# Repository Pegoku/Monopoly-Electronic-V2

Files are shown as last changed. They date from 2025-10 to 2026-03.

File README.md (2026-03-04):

# Monopoly-Electronic-V2
This is a recreation of the classic Monopoly Electronic Banking game using modern technology. The project utilizes an ESP32 microcontroller to handle game logic and interactions, along with a Touch LCD display and RFID readers for player identification and transactions.

## Demo

[Demo Video](https://youtube.com/shorts/_shUK3fcT8k?feature=share)

## Images

### Final product

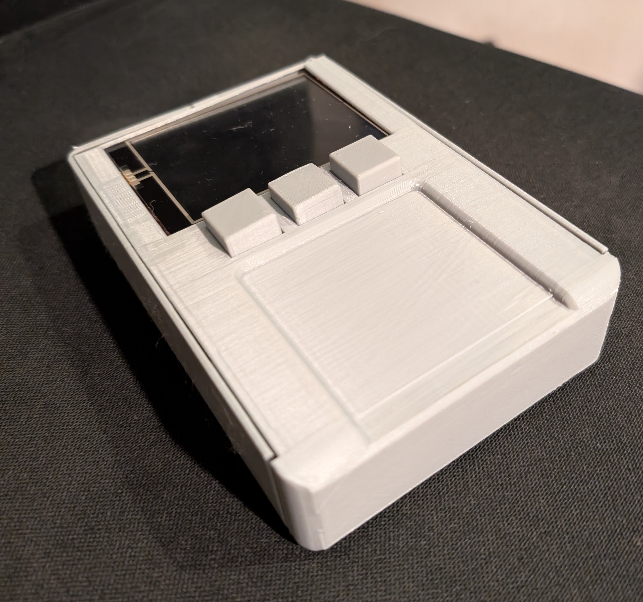
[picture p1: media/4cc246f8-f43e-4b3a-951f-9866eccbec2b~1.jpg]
Final Product


### CAD



<details>
<summary>Xray view - click to expand</summary>

Xray view

</details>

### PCB

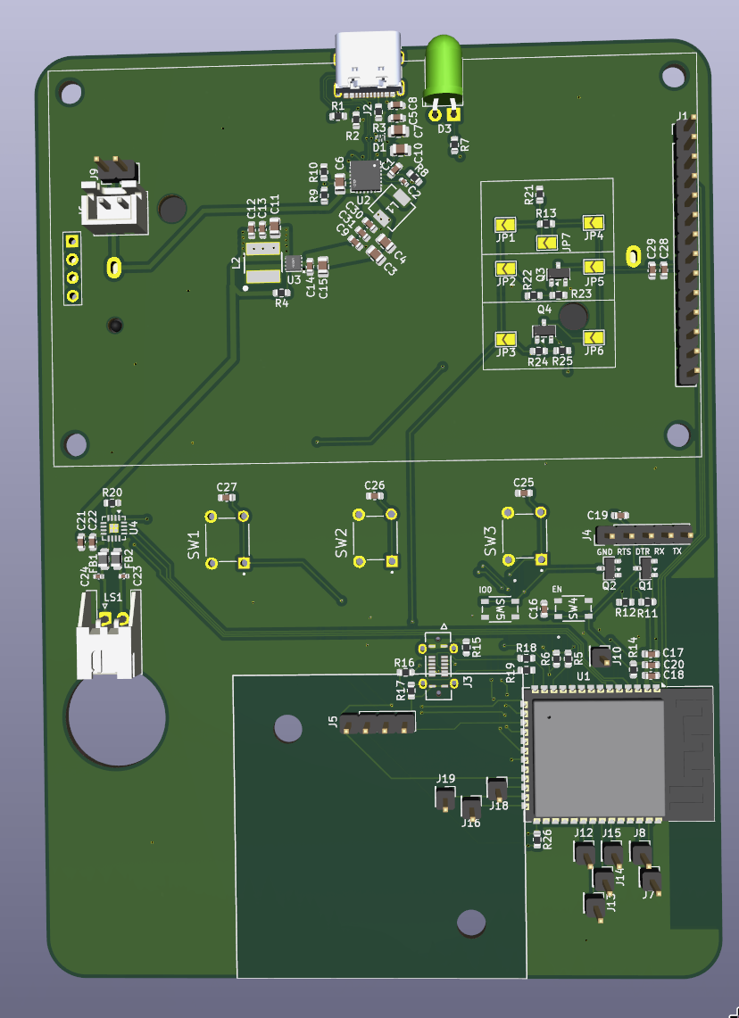
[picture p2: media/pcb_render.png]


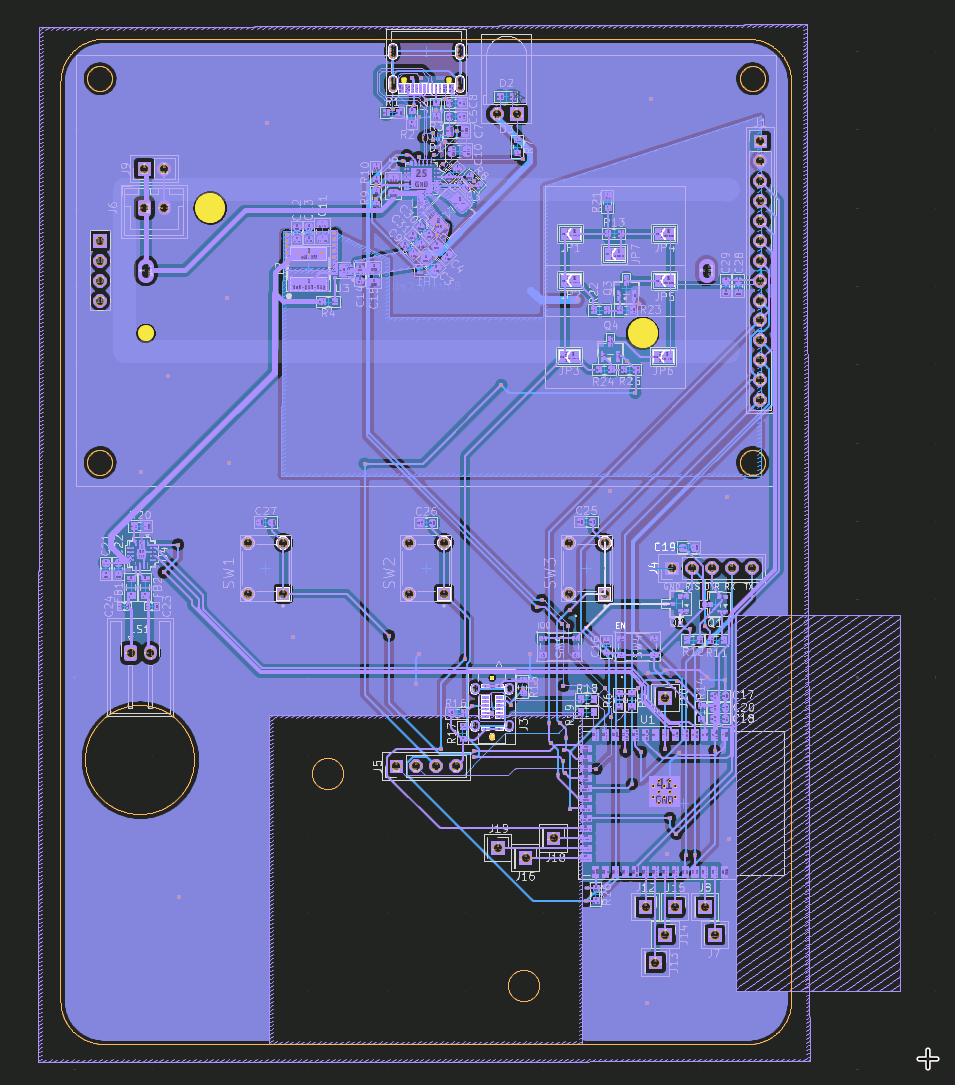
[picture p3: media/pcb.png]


<details>
<summary>Schematic - click to expand</summary>

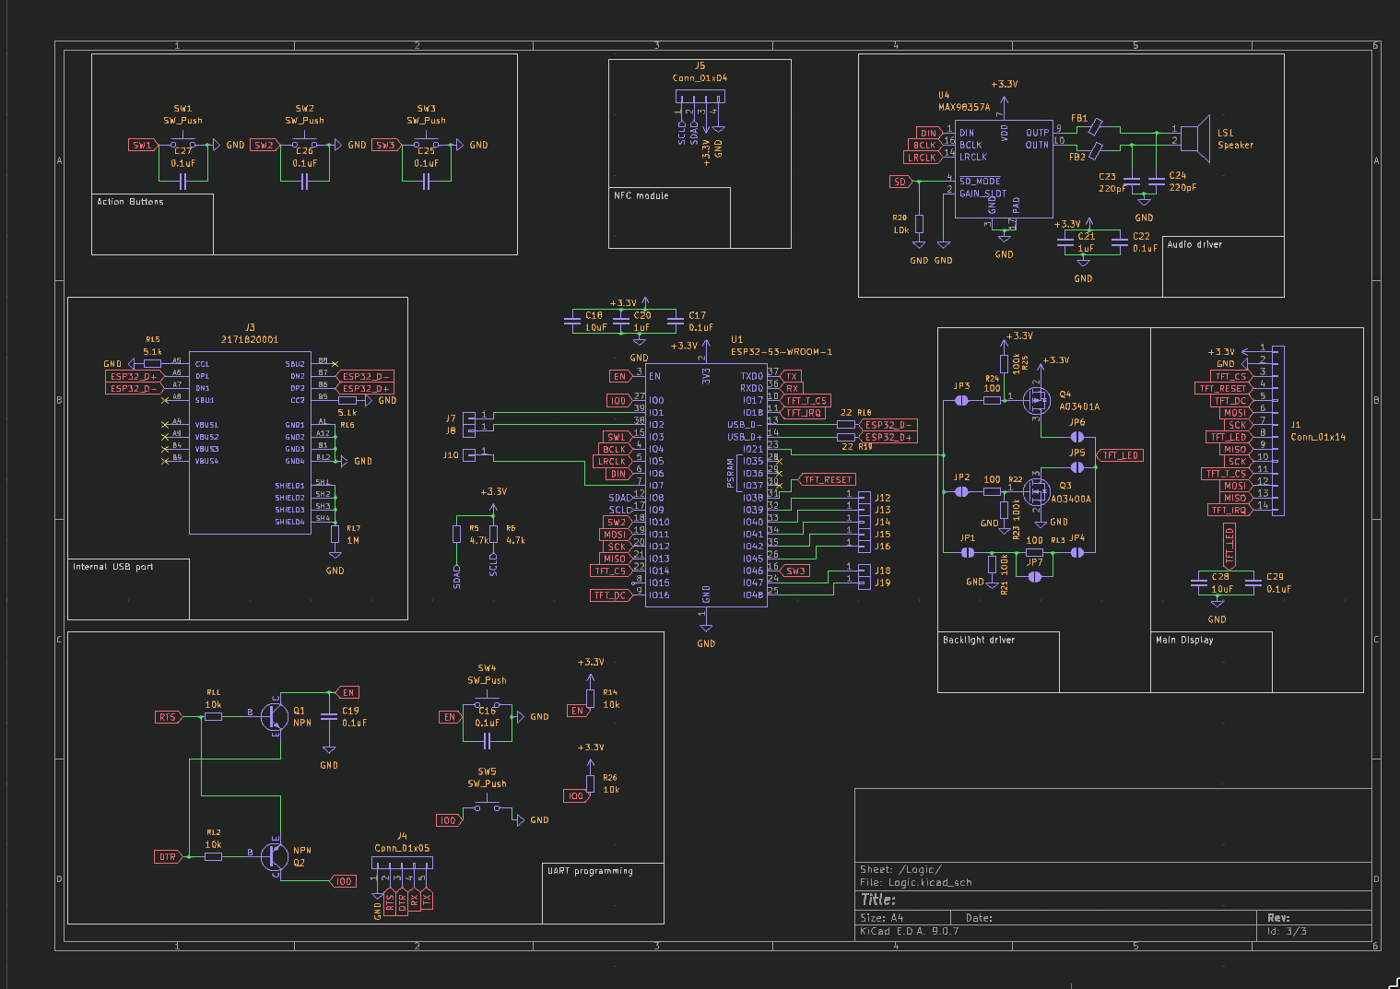
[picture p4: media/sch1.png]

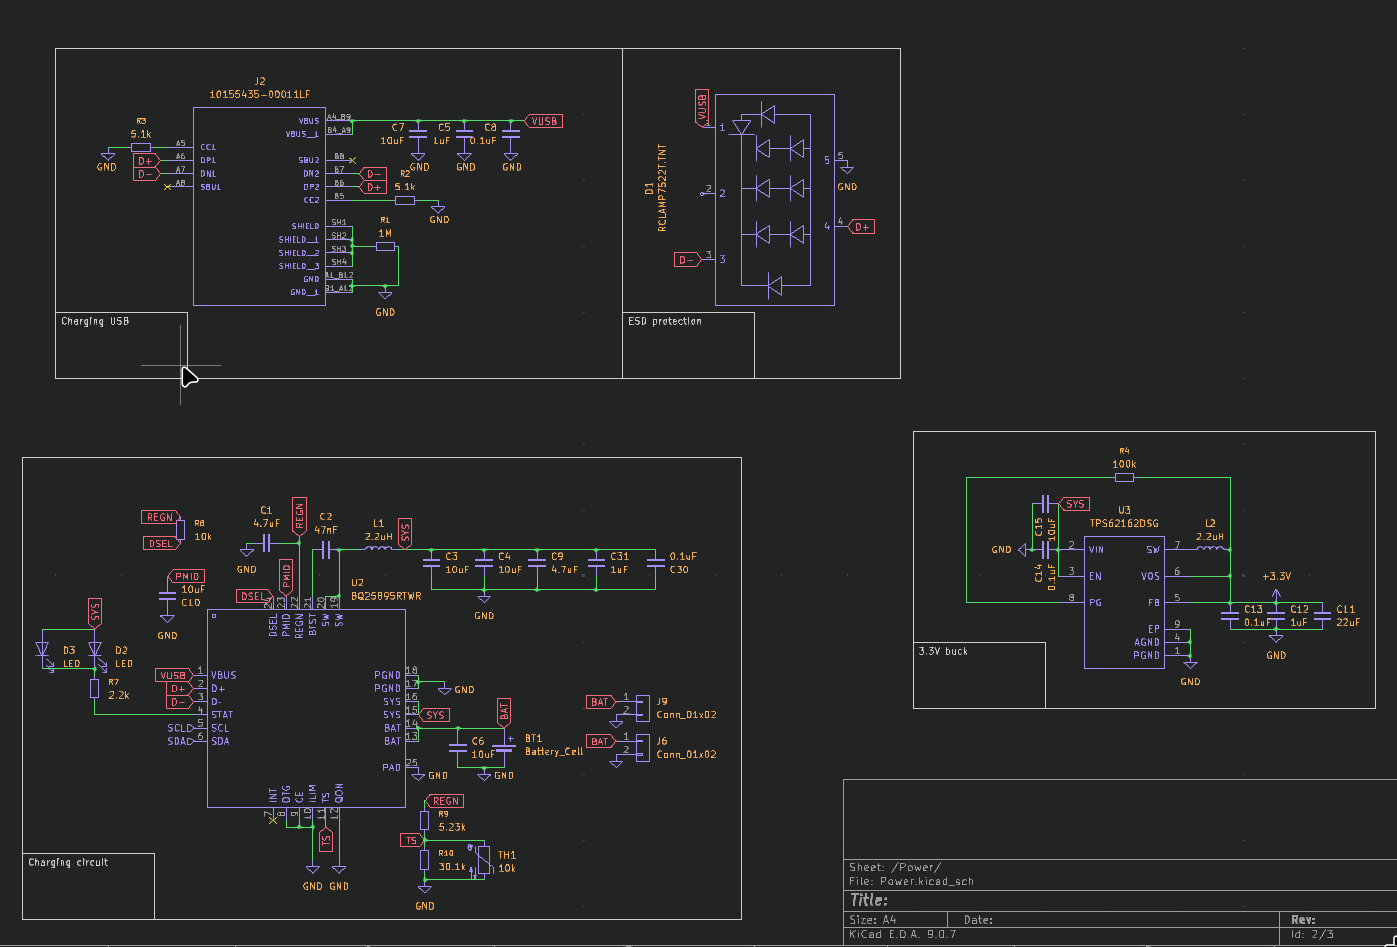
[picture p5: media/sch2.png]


</details>

## Features
- Electronic banking system using RFID cards for a more reliable process.
- Support for multiple players with individual RFID cards.
- Real-time game state updates displayed on the LCD.
- Sound effects for an immersive gaming experience.
- Customizable game rules and settings.

## UI

### Player registration

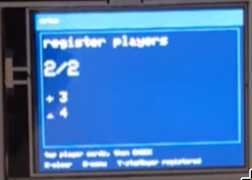
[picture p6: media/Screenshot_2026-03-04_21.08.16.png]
Player Registration


### Main game screen

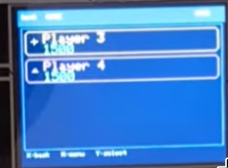
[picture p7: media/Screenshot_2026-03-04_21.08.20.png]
Main Game Screen


### Card interaction

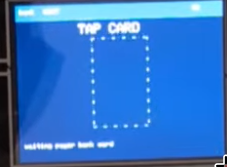
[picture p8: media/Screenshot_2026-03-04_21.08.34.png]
Card Interaction


## How the Game Works

Gameplay focuses on **NFC interaction instead of menus**.

Players throw the dice, and depending on where they land, they interact with the game console using their RFID cards. For example, if a player lands on a property, they can use their card to purchase it, or pay rent.

The game keeps track of each player's balance and properties, and updates the display accordingly. The use of RFID cards allows for a more seamless and engaging gaming experience, as players can quickly and easily interact with the game without navigating through complex menus. 

When a player has not enough money to pay rent or buy a property, they can choose to mortgage their properties or declare bankruptcy. The game will automatically handle these situations and update the game state accordingly.

If a player doesn't have enough money to pay rent, they will be bankrupt and removed from the game. The last player remaining with money wins the game.

### Card programming

To program the RFID cards, you can use the programming mode in the game console. Simply press the two side buttons simultaneously for 10 seconds to enter programming mode. Then, place the card you want to program on the console and follow the prompts on the LCD display to assign a player name, land.

## BOM (Bill of Materials)
| Index | MPN | Description | pack quantity | price | TOTAL  |
| ----- | --- | --- | --- | ----- | --- |
| 1 | BQ25895RTWR | IC BATT CHG LI-ION 1CELL 24WQFN | 2 | 6.58  | 178.39 |
| 2 | TPS62162DSGR | IC REG BUCK 3.3V 1A 8WSON | 2 | 3.14  | |
| 3 | RCLAMP7522T.TNT | TVS DIODE 5VWM 25VC SLP1007N5T | 2 | 3.14  | |
| 4 | ESP32-S3-WROOM-1-N8R8 | RF TXRX MOD BT WIFI PCB TH SMD | 2 | 12.26 | |
| 5 | NFC RFID Wireless Module | https://es.aliexpress.com/item/1005006837891461.html | 1 | 4.45  | |
| 6 | MF1 1k NFC card | https://es.aliexpress.com/item/1005006127590709.html | 50 | 12.91 | |
| 7 | 1043P | BATTERY HOLDER 18650 PC PIN | 2 | 5.62  | |
| 8 | F51L-1A7H1-11020 | CONN FFC FPC BOTTOM 20POS 1MM RA | 2 | 1.12  | |
| 9 | 10155435-00011LF | USB TYPE C R/A SMT 16PIN | 2 | 1.56  | |
| 10 | NSR10F20NXT5G | DIODE SCHOTTKY 20V 1A 2DSN | 2 | 0.3 | |
| 11 | SM5817PL-TP | DIODE SCHOTTKY 20V 1A SOD123FL | 3 | 0.45  | |
| 12 | BLM21PG221SN1D | FERRITE BEAD 220 OHM 0805 1LN | 3 | 0.33  | |
| 13 | GRM21BR61C106KE15K | CAP CER 10UF 16V X5R 0805 | 10 | 0.81  | |
| 14 | GRM21BR61A226ME51L | CAP CER 22UF 10V X5R 0805 | 10 | 1.14  | |
| 15 | GRM188R72A104KA35D | CAP CER 0.1UF 100V X7R 0603 | 17 | 1.48  | |
| 16 | 104CDMCCDS-220MC | FIXED IND 22UH 5A 66 MOHM SMD | 2 | 1.6 | |
| 17 | 74404054022 | FIXED IND 2.2UH 3.8A 19 MOHM SMD | 2 | 2.4 | |
| 18 | 104CDMCCDS-2R2MC | FIXED IND 2.2UH 15A 7 MOHM SMD | 2 | 1.6 | |
| 19 | SRP4020TA-2R2M | FIXED IND 2.2UH 4A 61 MOHM SMD | 2 | 2.04  | |
| 20 | BC847B | TRANS NPN 45V 0.1A SOT23-3 | 4 | 0.44  | |
| 21 | CL10B105KP8NNNC | CAP CER 1UF 10V X7R 0603 | 11 | 0.06  | |
| 22 | GRM188Z71A475ME15D | CAP CER 4.7UF 10V X7R 0603 | 11 | 1.34  | |
| 23 | GRM188Z71A475ME15D | CAP CER 4.7UF 10V X7R 0603 | 11 | 1.34  | |
| 24 | GRM1555C1H221JA01D | CAP CER 220PF 50V C0G/NP0 0402 | 11 | 0.36  | |
| 25 | GCJ188R71H473KA12D | CAP CER 0.047UF 50V X7R 0603 | 11 | 0.96  | |
| 26 | GRM155R71E473KA88D | CAP CER 0.047UF 25V X7R 0402 | 10 | 0.22  | |
| 27 | ERJ-3EKF1004V | RES SMD 1M OHM 1% 1/10W 0603 | 11 | 0.37  | |
| 28 | ERJ-PA3F5101V | RES SMD 5.1K OHM 1% 1/3W 0603 | 11 | 0.75  | |
| 29 | ERJ-PA3F1003V | RES SMD 100K OHM 1% 1/3W 0603 | 11 | 0.75  | |
| 30 | ERJ-PA3F4701V | RES SMD 4.7K OHM 1% 1/3W 0603 | 11 | 0.75  | |
| 31 | ERJ-PA3F2201V | RES SMD 2.2K OHM 1% 1/3W 0603 | 11 | 0.75  | |
| 32 | ERJ-PA3F1002V | RES SMD 10K OHM 1% 1/3W 0603 | 11 | 0.75  | |
| 33 | ERJ-3EKF5231V | RES SMD 5.23K OHM 1% 1/10W 0603 | 11 | 0.37  | |
| 34 | ERJ-PB3D3012V | RES SMD 30.1K OHM 0.5% 1/5W 0603 | 11 | 0.81  | |
| 35 | ERJ-3EKF1202V | RES SMD 12K OHM 1% 1/10W 0603 | 11 | 0.37  | |
| 36 | ERJ-3EKF22R0V | RES SMD 22 OHM 1% 1/10W 0603 | 11 | 0.37  | |
| 37 | NCU18XH103F6SRB | THERMISTOR NTC 10KOHM 3380K 0603 | 2 | 0.28  | |
| 38 | TL1105BF160Q | SWITCH TACTILE SPST-NO 0.05A 12V | 6 | 1.2 | |
| 39 | SKRPABE010 | SWITCH TACTILE SPST-NO 0.05A 16V | 4 | 0.84  | |
| 40 | SLR-56VRT32 | LED RED DIFFUSED T-1 3/4 T/H | 3 | 1.59  | |
| 41 | AO3400A | 30V 5.8A 35MR@10V,5.8A 1.4W 1.4V | 3 | 0.54  | |
| 42 | AO3401A | 30V 4.1A 65MR@10V,4.2A 350MW 1.3 | 3 | 0.6 | |
| 43 | Rubber Feets | https://es.aliexpress.com/item/1005007247599206.html | 4 | 3.22  | |
| 44 | PCB | JLCPCB | 1 | 41.59 | |
| 45 | M3x16 (DIN912) | https://es.aliexpress.com/item/1005007118809249.html | 55 | 4.67  | |
| 46 | M2.5x6 (DIN7991) | https://es.aliexpress.com/item/1005007118809249.html | 55 | 4.19  | |
| 47 | heatset inserts M2.5x3.5 | https://es.aliexpress.com/item/1005007342105110.html | 50 | 3.4 | |
| 48 | heatset inserts M3x4.2 | https://es.aliexpress.com/item/1005007342105110.html | 50 | 3.92  | |
| 49 | 8R 0.5W 40mm Speaker | https://es.aliexpress.com/item/1005007949154095.html | 1 | 3.51  | |
| 50 | 3.2" ST7789 with touch | https://es.aliexpress.com/item/1005009929917954.html | 1 | 10.37 | |
| 51 | heatset insert pinecil | https://es.aliexpress.com/item/1005008145530885.html | 1 | 11.89 | |
| 52 | Digikey VAT | | 1 | 12.89 | |

## License

This work is licensed under a
[Creative Commons Attribution-NonCommercial 4.0 International License][cc-by-nc].

[][cc-by-nc]

[cc-by-nc]: https://creativecommons.org/licenses/by-nc/4.0/
[cc-by-nc-image]: https://licensebuttons.net/l/by-nc/4.0/88x31.png
[cc-by-nc-shield]: https://img.shields.io/badge/License-CC%20BY--NC%204.0-lightgrey.svg

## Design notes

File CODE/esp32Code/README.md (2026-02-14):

# ESP32 Monopoly Electronic Banking Firmware

Minimal card-driven firmware for ESP32 + ST7789 + PN532, matching the web emulator flow.

## Build

```bash
pio run
```

## Flash

```bash
pio run -t upload
```

## Implemented modules

- `src/nfc_manager.cpp`
- `src/card_manager.cpp`
- `src/game_logic.cpp`
- `src/display_ui.cpp`
- `src/battery_manager.cpp`
- `src/sound_manager.cpp`

## NFC block layout (Mifare Classic)

- Player bank card: block `4`
- Property card: block `8`
- Event card: block `12`

Each block stores:

- bytes `[0..2]`: magic `MB2`
- byte `[3]`: version
- byte `[4]`: card type
- remaining bytes: card payload

## Notes

- Game state follows card-driven state machine (`HOME`, `WAIT_CARD`, `PROPERTY_*`, `EVENT`, `AUCTION`, `DEBT`, `GO`, `JAIL`, `WINNER`).
- UI is intentionally sparse and monochrome-like, based on your reference photos.
- Property ownership/rent level are read/written from property cards.

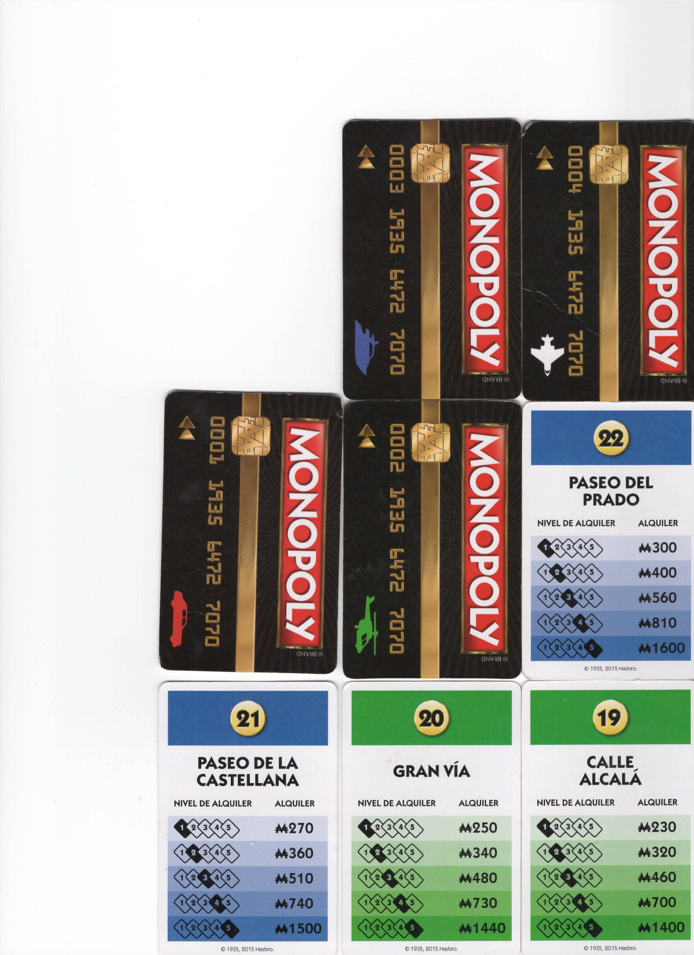
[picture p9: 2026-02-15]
CODE/CardGenerator/reference_page-3.png

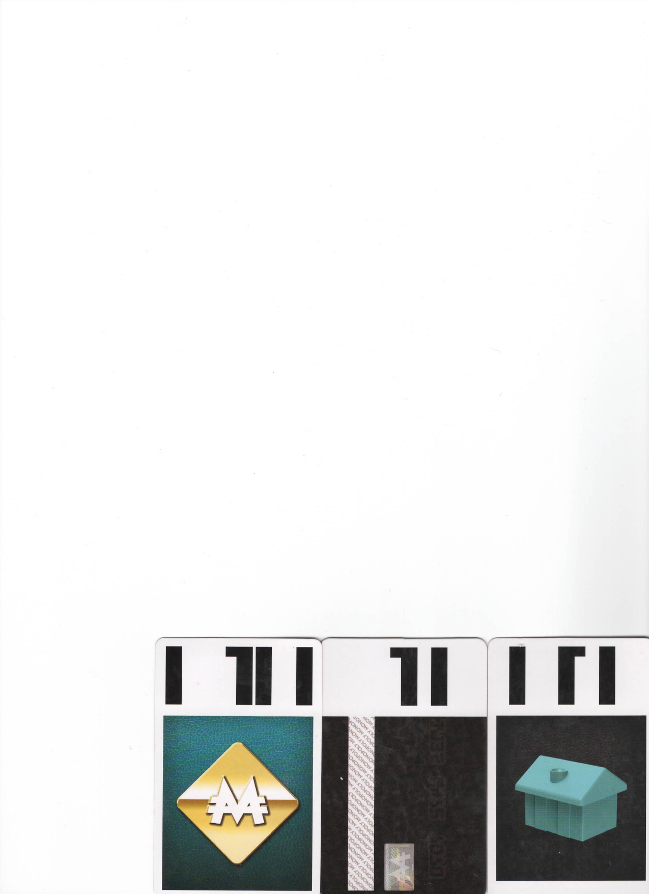
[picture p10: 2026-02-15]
CODE/CardGenerator/reference_page-4.png

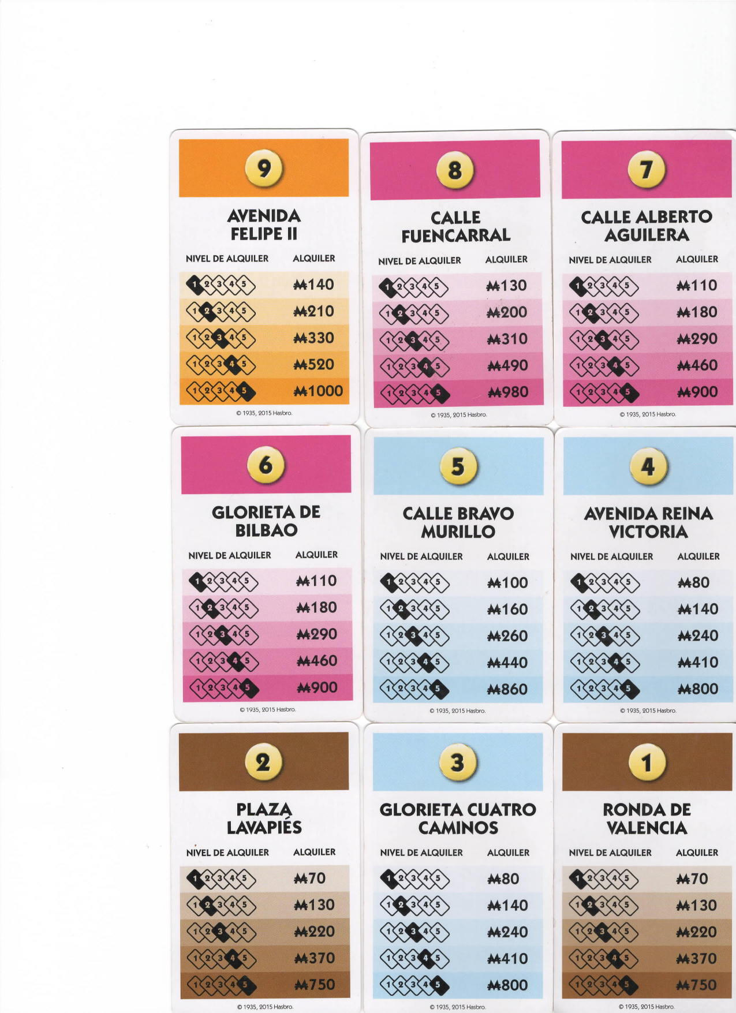
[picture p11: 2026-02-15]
CODE/CardGenerator/reference_page-1.png

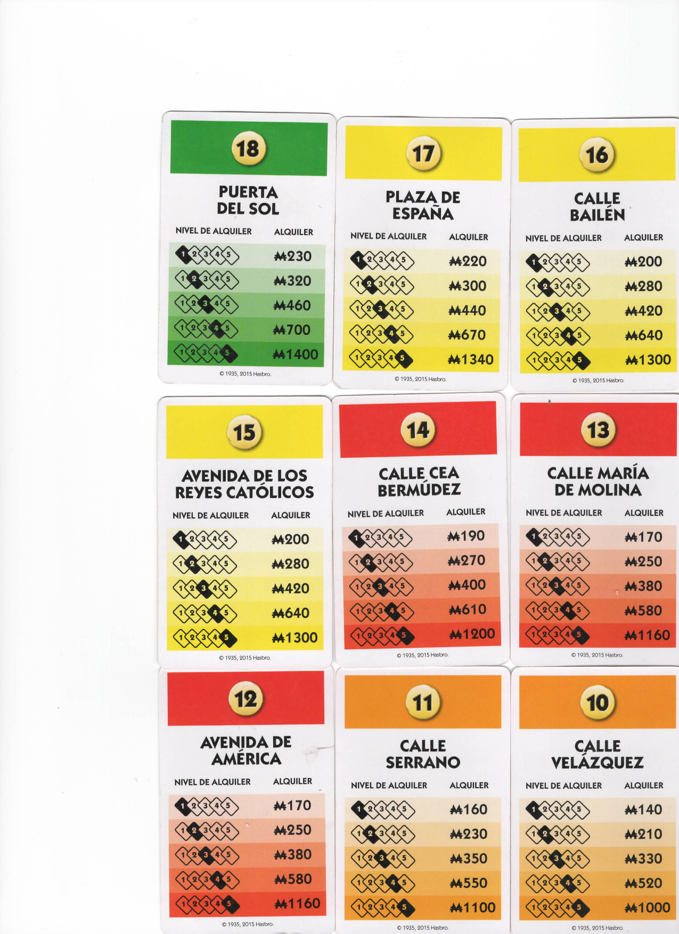
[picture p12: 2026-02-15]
CODE/CardGenerator/reference_page-2.png

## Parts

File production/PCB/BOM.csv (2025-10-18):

Designator | Footprint | Quantity | Value
BT1 | BAT-TH_1043P | 1 | Battery_Cell
C1, C9 | 603 | 2 | 4.7uF
C10, C15, C3, C4, C6, C7 | 805 | 6 | 10uF
C11 | 805 | 1 | 22uF
C12, C20, C21, C31, C5 | 603 | 5 | 1uF
C13, C14, C16, C17, C19, C22, C25, C26, C27, C29, C30, C8 | 603 | 12 | 0.1uF
C18, C28 | 603 | 2 | 10uF
C2 | 402 | 1 | 47nF
C23, C24 | 402 | 2 | 220pF
D1 | SLP1007N5T_L1.0-W0.7-P0.35-BL | 1 | RCLAMP7522T.TNT
D2 | 603 | 1 | LED
D3 | LED_D5.0mm_Horizontal_O1.27mm_Z3.0mm | 1 | LED
FB1, FB2 | 805 | 2 | BLM21PG221SN1D
J1 | 240X320 TFT 3.2 display | 1 | Conn_01x14
J10, J12, J13, J14, J15, J16, J18, J19, J7, J8 | PinHeader_1x01_P2.54mm_Vertical | 10 | Conn_01x01
J2 | AMPHENOL_10155435-00011LF | 1 | 10155435-00011LF
J3 | MOLEX_2171820001 | 1 | 2171820001
J4 | PinHeader_1x05_P2.54mm_Vertical | 1 | Conn_01x05
J5 | PinHeader_1x04_P2.54mm_Vertical | 1 | Conn_01x04
J6 | JST_XH_B2B-XH-A_1x02_P2.50mm_Vertical | 1 | Conn_01x02
J9 | PinHeader_1x02_P2.54mm_Vertical | 1 | Conn_01x02
L1 | IND_SRP4020TA_BRN | 1 | 2.2uH
L2 | WE-LQS_5040 | 1 | 2.2uH
LS1 | JST_XH_S2B-XH-A-1_1x02_P2.50mm_Horizontal | 1 | Speaker
Q1, Q2 | SOT-23-231 | 2 | NPN
Q3 | SOT-23 | 1 | AO3400A
Q4 | SOT-23 | 1 | AO3401A
R1, R17 | 603 | 2 | 1M
R10 | 603 | 1 | 30.1k
R11, R12, R14, R20, R26, R8, TH1 | 603 | 7 | 10k
R13, R22, R24 | 603 | 3 | 100
R15, R16, R2, R3 | 603 | 4 | 5.1k
R18, R19 | 603 | 2 | 22
R21, R23, R25, R4 | 603 | 4 | 100k
R5, R6 | 603 | 2 | 4.7k
R7 | 603 | 1 | 2.2k
R9 | 603 | 1 | 5.23k
SW1, SW2, SW3 | SW_TL1105BF160Q | 3 | SW_Push
SW4, SW5 | SW4_SKRPABE010_ALPS | 2 | SW_Push
U1 | ESP32-S3-WROOM-1 | 1 | ESP32-S3-WROOM-1
U2 | QFN-24_L4.0-W4.0-P0.50-TL-EP2.7 | 1 | BQ25895RTWR
U3 | WSON-8_L2.0-W2.0-P0.50-TL-EP | 1 | TPS62162DSG
U4 | TQFN-16-1EP_3x3mm_P0.5mm_EP1.23x1.23mm | 1 | MAX98357A

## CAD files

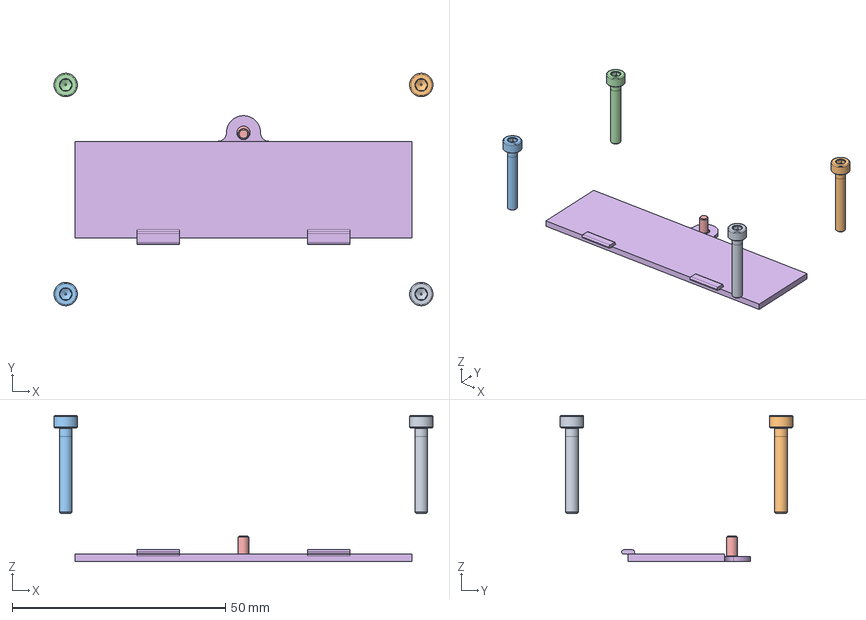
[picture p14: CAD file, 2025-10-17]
CAD/MAIN.FCStd
88.8 x 54.5 x 34.3 mm
M3x20-Screw
M3x20-Screw004
M3x20-Screw005
M3x20-Screw006
M2.5x6-Screw

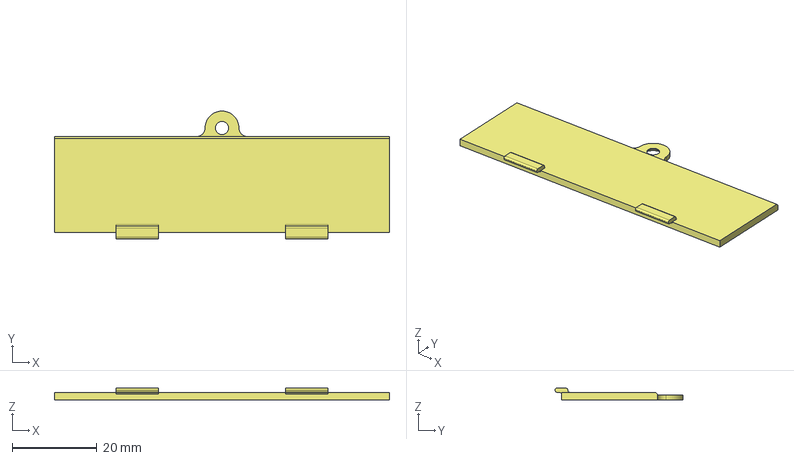
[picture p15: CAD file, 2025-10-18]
production/CAD/CaseBatteryTab.step
79.0 x 30.2 x 2.80 mm

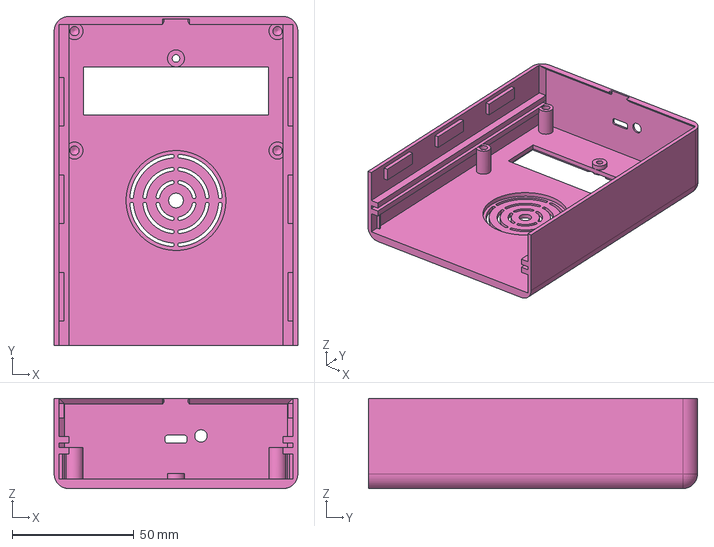
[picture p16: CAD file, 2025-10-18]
production/CAD/CaseBase.step
100.0 x 135.0 x 37.0 mm

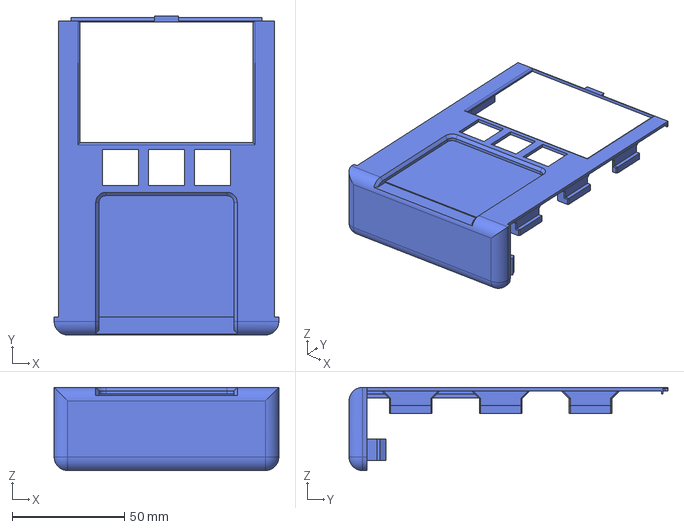
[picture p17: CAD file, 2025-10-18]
production/CAD/CaseCover.step
100.0 x 142.0 x 37.0 mm

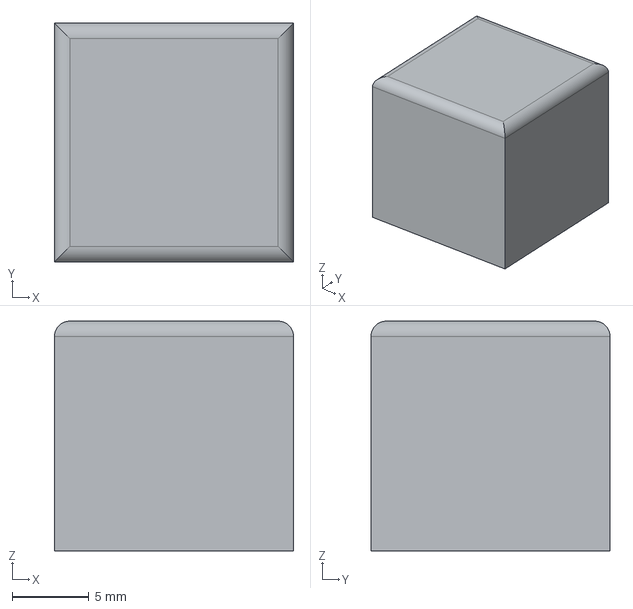
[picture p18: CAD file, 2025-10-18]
production/CAD/CaseButton.step
15.6 x 15.6 x 15.0 mm

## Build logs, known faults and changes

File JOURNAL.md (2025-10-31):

<!--
  ===================    !!READ THIS NOTICE!!   ====================
  DO NOT edit this file manually. Your changes WILL BE OVERWRITTEN!
  This journal is auto generated and updated by Hack Club Blueprint.
  To edit this file, please edit your journal entries on Blueprint.
  ==================================================================
-->

## 10/3/2025 - Simple draft of the project  

I drew a simple draft of the project. 
For this project, I would like to have the following features:
- MCU (maybe Wi-Fi for future mobile/web integration)
- NFC reader
- TFT display
- Speaker
- Action buttons
- Battery (at least a few hours of battery life, maybe an 18650 or multiple AA batteries)



## 10/4/2025 - Research possible parts  

I've been searching for the possible parts I could use for my project. I've seen many options, some more expensive, others cheaper. I have ended up selecting most of the parts from Digikey, due to the huge variety and fast shipping.
I've created a [digikey list](https://www.digikey.es/en/mylists/list/QVK6J72RAV) with all the parts that will be used.
[https://www.digikey.es/en/mylists/list/QVK6J72RAV](https://www.digikey.es/en/mylists/list/QVK6J72RAV)
  

## 10/6/2025 11 AM - Work on the Power/battery part of the schematic  

I have been working on the battery part of the schematic.
I have wired most of the BQ25895RTWR, and USB-C port. Only the 3.3V buck is left.
I arrived to the conclusion about not needing the 5V from the BQ25895RTWR, as everything will be running from 3.3V, so I disabled it.


## 10/6/2025 8 PM - Work on the Logic part of the schematic  

I've been working on the Logic part of the shematic. The programming part should be done, I used a vertical USB-C port I'll have hidden inside, and regular UART as a fallback.
I also added an I2S Audio driver (MAX98357A) as I didn't want to just use PWM, but didn't need something too fancy for simple sound effects.
Now I'll just need to add a display, which I'll be changing to a bigger one. Maybe, I'll get one with touch support



## 10/7/2025 - Find a possible suitable LCD  

After all, I decided for an SPI TFT LCD. I'll be going with a 3.2" touch ST7789 SPI display. it seems to be big enough, and have more than enough resolution for my project. Also, it seems to be supported with some libraries.
It also has touch, just in case I ever want to use it.


## 10/8/2025 - Finish Schematic routing  

I finished all the schematic routing (PCB, NFC, etc). The display seemed hard, but it really was just two SPI devices (Display and Touch).
I think everything should be done now. I only need to select all components (resistors, capacitors, etc) so I can use the correct footprints.




## 10/10/2025 - Assign footprints + backlight driving options  

I assigned all the necessary footprints to the symbols, and I also chose which parts I will be using for the PCB. I added all of them to the [Digikey BOM](https://www.digikey.es/en/mylists/list/QVK6J72RAV).
Also, as I don't currently have the display, nor, know how the LED backlight is connected, I added multiple driving circuits. They are all disabled by default (have to use jumpers). And when I get all the components, I will use the correct driver method.



## 10/11/2025 10 AM - Groups to the schematic and start placing components  

I have reordered the schematic so I can more easily reference the components and, at a glance, find them.
I've used rectangles and text so I can name all the groups.





Then, I've started placing the components in the PCB. I'll start with what I always do, group the components and try to place them with their "ideal" placement.
This is what I've got so far:







## 10/11/2025 8 PM - Finish placing the components  

I finished placing all the components in their "ideal" place. Due to the bigger than firstly planned display, the PCB ended up being 93.3 x 128.35 mm. which isn't a lot bigger than intented, but it will make the final device bigger, not a huge dealbreaker, though.



## 10/12/2025 - Start routing top part of the pcb  

I have started routing part of the pcb. as I already had all the components placed, I only have to connect them, which isn't too hard. I'm also using copper pours for some parts of the pcb, eg. buck.
For now, I've routed the usb charge connector, battery circuit and charger and buck.



## 10/13/2025 - Finish routing the PCB  

I finished routing all the PCB. It should now be done. I will now start designing the case. I will try to make it similar to the drawing I did before (first journal entry), while also having the essence of the original [Monopoly Electronic i have](https://imgs.search.brave.com/97KW8I4h7B_5Km5_sD36x9mR6GnvyAEScB285sH_O2Q/rs:fit:860:0:0:0/g:ce/aHR0cHM6Ly9pLmVi/YXlpbWcuY29tL2lt/YWdlcy9nLzBPQUFB/T1N3aEExbWx3Y0sv/c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).





## 10/15/2025 11 AM - Start Cadding  

I have started the CAD design. I've added a speaker grill (spent too much time making it look good, battery pocket for easy battery replacement (if necessary) and pcb "rails" so the pcb can easily be mounted. 
For now I'll be doing only the "raw" parts of the case. then I'll add more complex/visual features.

This is what I've got so far:





## 10/15/2025 7 PM - Finish base and design clipping mechanism  

I've finished designing the base, and I've started designing the cover of the case. I'm going with a "slide and click" mechanism. This way it will be easy to assemble, and also, there won't be any visible screws, which is a must (if I can) for this design.



PS: this is going to be VERY overengineered... 😭  

## 10/17/2025 - Finish CAD (Hopefully)  

It took longer than expected, but, finally, after a lot of time and overengineering, I finished all the CAD!
I tried to keep as many of the visual features as I could while making sure it actually works.
I ~~think~~ know it could have been made a lot simpler, but I wanted to challenge myself.

This is the final result.





## 10/18/2025 - Prepare GitHub Repo for submitting  

I got the repo ready for submitting. Luckily I alredy had most of the files, exports, etc done. I just had to copy them to the correct folders, write a README.md, add images, check, export and convert to MarkDown the BOM, and write this journal entry.

REPO: https://github.com/Pegoku/Monopoly-Electronic-V2



## 10/19/2025 - Learning LVGL  

I had to have some code for this project, so I could submit it, so I started to learn LVGL, so when I receive the parts, I can assemble them and can start to use it to test the display. I didn't do the full game for now, as I don't want to build it in regular cpp (not arduino framework) due to it maybe not working as intended on the final device.

For now, I did a simple 5 button test. When a button is pressed, a random number is generated. This is a start, and I will be able to use what I learnt for this for the final build.


## 10/31/2025 - Tests before order  

Before I order the PCB, I wanted to do some tests with the display, so I bought an esp32-S3 devboard and a display so I could learn LVGL, and check the schematic is correct.

I was able to get the display to work!
PXL_20251030_213944654.MP

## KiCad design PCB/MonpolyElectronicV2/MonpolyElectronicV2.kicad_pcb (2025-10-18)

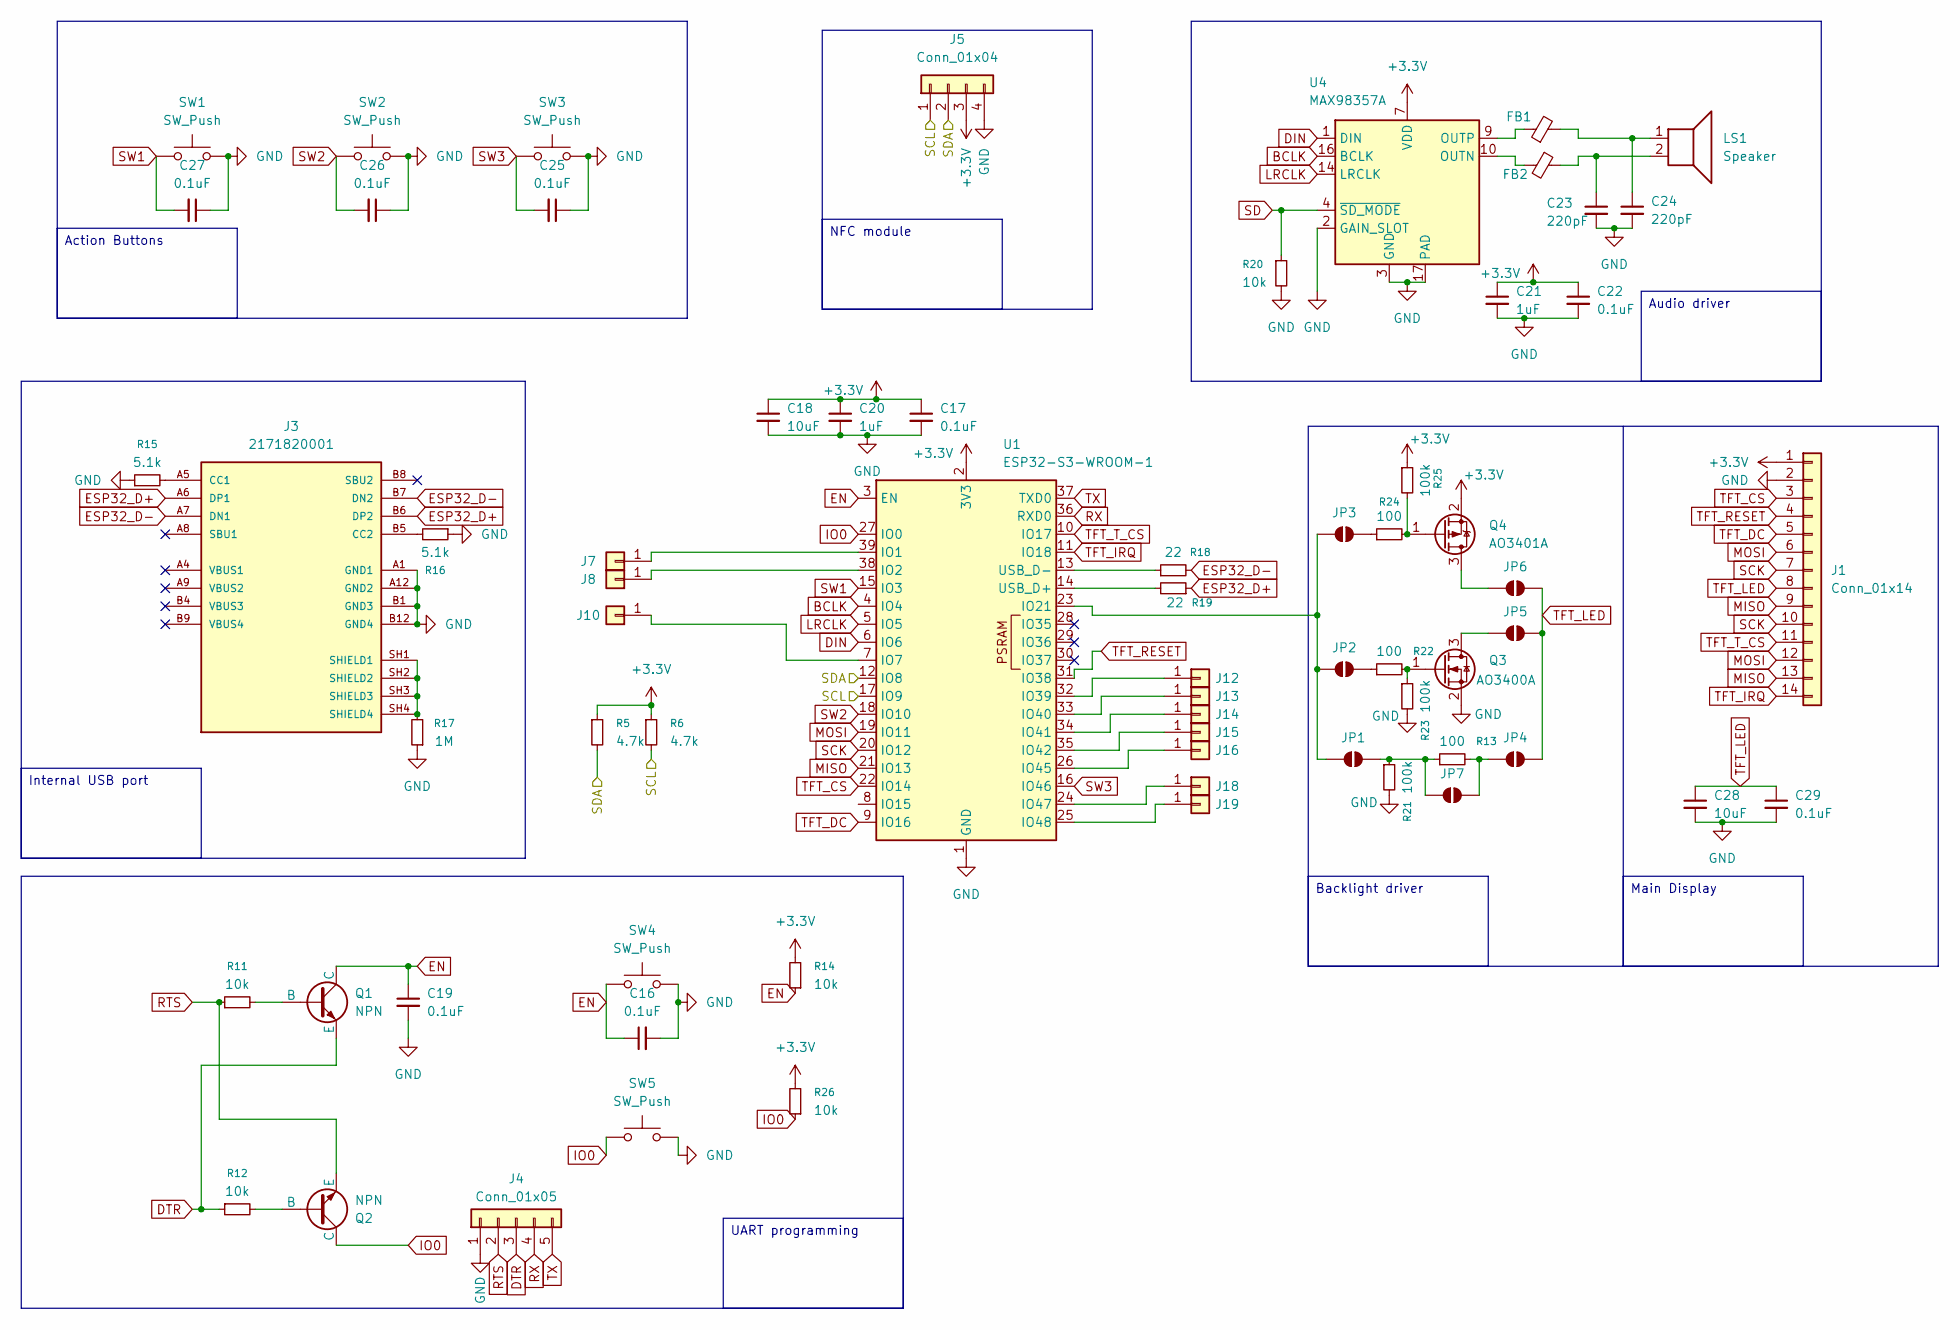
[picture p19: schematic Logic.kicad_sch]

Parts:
C16, C17, C19, C22, C25, C26, C27, C29: 0.1uF; C_0603_1608Metric
C18, C28: 10uF; C_0603_1608Metric
C20, C21: 1uF; C_0603_1608Metric
C23, C24: 220pF; C_0402_1005Metric
FB1, FB2: BLM21PG221SN1D; L_0805_2012Metric
J1: Conn_01x14; 240X320 TFT 3.2 display
J3: 2171820001; MOLEX_2171820001; PARTREV B
J4: Conn_01x05; PinHeader_1x05_P2.54mm_Vertical
J5: Conn_01x04; PinHeader_1x04_P2.54mm_Vertical
J7, J8, J10, J12, J13, J14, J15, J16, J18, J19: Conn_01x01; PinHeader_1x01_P2.54mm_Vertical
JP1, JP2, JP3, JP4, JP5, JP6, JP7: SolderJumper_2_Open; SolderJumper-2_P1.3mm_Open_TrianglePad1.0x1.5mm
LS1: Speaker; JST_XH_S2B-XH-A-1_1x02_P2.50mm_Horizontal
Q1, Q2: NPN; SOT-23-231
Q3: AO3400A; SOT-23
Q4: AO3401A; SOT-23
R5, R6: 4.7k; R_0603_1608Metric
R11, R12, R14, R20, R26: 10k; R_0603_1608Metric
R13, R22, R24: 100; R_0603_1608Metric
R15, R16: 5.1k; R_0603_1608Metric
R17: 1M; R_0603_1608Metric
R18, R19: 22; R_0603_1608Metric
R21, R23, R25: 100k; R_0603_1608Metric
SW1, SW2, SW3: SW_Push; SW_TL1105BF160Q
SW4, SW5: SW_Push; SW4_SKRPABE010_ALPS
U1: ESP32-S3-WROOM-1
U4: MAX98357A; TQFN-16-1EP_3x3mm_P0.5mm_EP1.23x1.23mm

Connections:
+3.3V: C17.1, C18.1, C20.1, C21.1, C22.1, J1.1, J5.3, Q4.2 (S), R5.1, R6.1, R14.2, R25.1, R26.2, U1.2 (3V3), U4.7 (VDD), U4.8 (VDD); also elsewhere on the board
/Logic/SCL: J5.1, R6.2, U1.17 (IO9); also elsewhere on the board
/Logic/SDA: J5.2, R5.2, U1.12 (IO8); also elsewhere on the board
BCLK: U1.4 (IO4), U4.16 (BCLK)
DIN: U1.6 (IO6), U4.1 (DIN)
DTR: J4.3, Q1.3 (E), R12.1
EN: C16.1, C19.1, Q1.1 (C), R14.1, SW4.1, U1.3 (EN)
ESP32_D+: J3.A6 (DP1), J3.B6 (DP2), R19.1
ESP32_D-: J3.A7 (DN1), J3.B7 (DN2), R18.2
GND: C16.2, C17.2, C18.2, C19.2, C20.2, C21.2, C22.2, C23.2, C24.2, C25.1, C26.1, C27.1, C28.2, C29.2, J1.2, J3.A1 (GND1), J3.A12 (GND2), J3.B1 (GND3), J3.B12 (GND4), J4.1, J5.4, Q3.2 (S), R15.1, R16.1, R17.1, R20.2, R21.2, R23.2, SW1.2, SW2.2, SW3.2, SW4.2, SW5.2, U1.1 (GND), U1.40 (GND), U1.41 (GND), U4.2 (GAIN_SLOT), U4.3 (GND), U4.11 (GND), U4.15 (GND), U4.17 (PAD); also elsewhere on the board
IO0: Q2.1 (C), R26.1, SW5.1, U1.27 (IO0)
LRCLK: U1.5 (IO5), U4.14 (LRCLK)
MISO: J1.9, J1.13, U1.21 (IO13)
MOSI: J1.6, J1.12, U1.19 (IO11)
unnamed: C23.1, FB2.1, LS1.2
unnamed: C24.1, FB1.2, LS1.1
unnamed: J3.A5 (CC1), R15.2
unnamed: J3.B5 (CC2), R16.2
unnamed: J3.SH1 (SHIELD1), J3.SH2 (SHIELD2), J3.SH3 (SHIELD3), J3.SH4 (SHIELD4), R17.2
unnamed: J7.1, U1.39 (IO1)
unnamed: J8.1, U1.38 (IO2)
unnamed: J10.1, U1.7 (IO7)
unnamed: J12.1, U1.32 (IO39)
unnamed: J13.1, U1.33 (IO40)
unnamed: J14.1, U1.34 (IO41)
unnamed: J15.1, U1.35 (IO42)
unnamed: J16.1, U1.26 (IO45)
unnamed: J18.1, U1.24 (IO47)
unnamed: J19.1, U1.25 (IO48)
unnamed: JP1.1 (A), JP7.2 (B), R13.1, R21.1
unnamed: JP1.2 (B), JP2.2 (B), JP3.2 (B), U1.23 (IO21)
unnamed: JP2.1 (A), R22.1
unnamed: JP3.1 (A), R24.1
unnamed: JP4.2 (B), JP7.1 (A), R13.2
unnamed: JP5.2 (B), Q3.3 (D)
unnamed: JP6.2 (B), Q4.3 (D)
unnamed: Q1.2 (B), R11.2
unnamed: Q2.2 (B), R12.2
unnamed: Q3.1 (G), R22.2, R23.1
unnamed: Q4.1 (G), R24.2, R25.2
unnamed: R19.2, U1.14 (USB_D+)
unnamed: R18.1, U1.13 (USB_D-)
unnamed: FB2.2, U4.10 (OUTN)
unnamed: FB1.1, U4.9 (OUTP)
RTS: J4.2, Q2.3 (E), R11.1
RX: J4.4, U1.36 (RXD0)
SCK: J1.7, J1.10, U1.20 (IO12)
SD: R20.1, U4.4 (~SD_MODE)
SW1: C27.2, SW1.1, U1.15 (IO3)
SW2: C26.2, SW2.1, U1.18 (IO10)
SW3: C25.2, SW3.1, U1.16 (IO46)
TFT_CS: J1.3, U1.22 (IO14)
TFT_DC: J1.5, U1.9 (IO16)
TFT_IRQ: J1.14, U1.11 (IO18)
TFT_LED: C28.1, C29.1, J1.8, JP4.1 (A), JP5.1 (A), JP6.1 (A)
TFT_RESET: J1.4, U1.31 (IO38)
TFT_T_CS: J1.11, U1.10 (IO17)
TX: J4.5, U1.37 (TXD0)

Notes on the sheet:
Internal USB port
Main Display
Audio driver
UART programming
Backlight driver
Action Buttons
NFC module

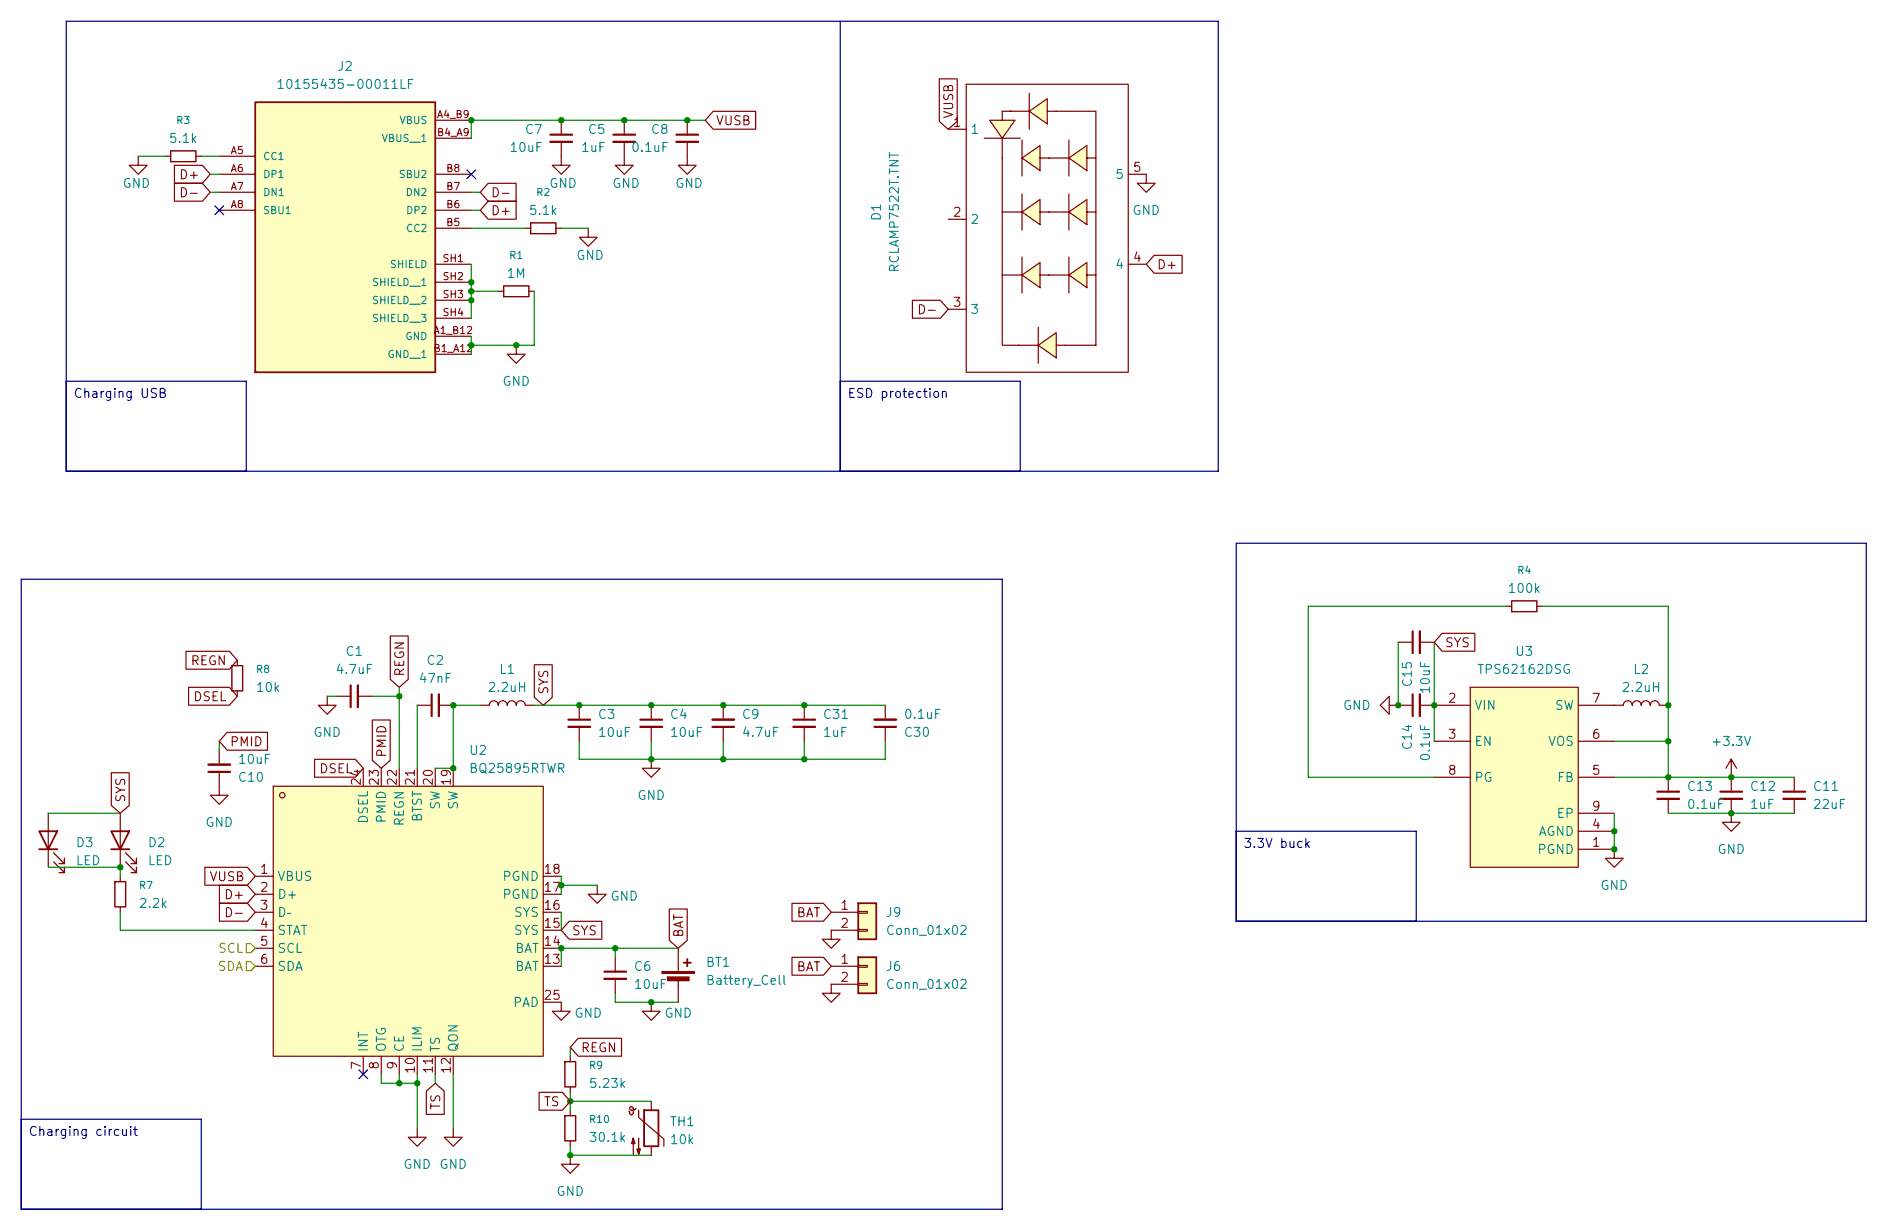
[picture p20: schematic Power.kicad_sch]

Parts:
BT1: Battery_Cell; BAT-TH_1043P
C1, C9: 4.7uF; C_0603_1608Metric
C2: 47nF; C_0402_1005Metric
C3, C4, C6, C7, C10, C15: 10uF; C_0805_2012Metric
C5, C12, C31: 1uF; C_0603_1608Metric
C8, C13, C14, C30: 0.1uF; C_0603_1608Metric
C11: 22uF; C_0805_2012Metric
D1: RCLAMP7522T.TNT; SLP1007N5T_L1.0-W0.7-P0.35-BL; LCSC Part C1977186
D2: LED; LED_0603_1608Metric
D3: LED; LED_D5.0mm_Horizontal_O1.27mm_Z3.0mm
J2: 10155435-00011LF; AMPHENOL_10155435-00011LF; PARTREV C
J6: Conn_01x02; JST_XH_B2B-XH-A_1x02_P2.50mm_Vertical
J9: Conn_01x02; PinHeader_1x02_P2.54mm_Vertical
L1: 2.2uH; IND_SRP4020TA_BRN
L2: 2.2uH; WE-LQS_5040
R1: 1M; R_0603_1608Metric
R2, R3: 5.1k; R_0603_1608Metric
R4: 100k; R_0603_1608Metric
R7: 2.2k; R_0603_1608Metric
R8: 10k; R_0603_1608Metric
R9: 5.23k; R_0603_1608Metric
R10: 30.1k; R_0603_1608Metric
TH1: 10k; R_0603_1608Metric
U2: BQ25895RTWR; QFN-24_L4.0-W4.0-P0.50-TL-EP2.7; LCSC Part C80200
U3: TPS62162DSG; WSON-8_L2.0-W2.0-P0.50-TL-EP; LCSC Part C40256

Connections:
+3.3V: C11.1, C12.1, C13.1, L2.2, R4.2, U3.5 (FB), U3.6 (VOS); also elsewhere on the board
/Logic/SCL: U2.5 (SCL); also elsewhere on the board
/Logic/SDA: U2.6 (SDA); also elsewhere on the board
BAT: BT1.1 (+), C6.1, J6.1, J9.1, U2.13 (BAT), U2.14 (BAT)
D+: D1.4, J2.A6 (DP1), J2.B6 (DP2), U2.2 (D+)
D-: D1.3, J2.A7 (DN1), J2.B7 (DN2), U2.3 (D–)
DSEL: R8.2, U2.24 (DSEL)
GND: BT1.2 (-), C1.1, C3.2, C4.2, C5.2, C6.2, C7.2, C8.2, C9.1, C10.1, C11.2, C12.2, C13.2, C14.1, C15.1, C30.1, C31.2, D1.5, J2.A1_B12 (GND), J2.B1_A12 (GND__1), J6.2, J9.2, R1.2, R2.2, R3.1, R10.2, TH1.2, U2.8 (OTG), U2.9 (CE), U2.10 (ILIM), U2.12 (QON), U2.17 (PGND), U2.18 (PGND), U2.25 (PAD), U3.1 (PGND), U3.4 (AGND), U3.9 (EP); also elsewhere on the board
unnamed: C2.2, L1.1, U2.19 (SW), U2.20 (SW)
unnamed: D2.1 (K), D3.1 (K), R7.1
unnamed: J2.A5 (CC1), R3.2
unnamed: J2.B5 (CC2), R2.1
unnamed: J2.SH1 (SHIELD), J2.SH2 (SHIELD__1), J2.SH3 (SHIELD__2), J2.SH4 (SHIELD__3), R1.1
unnamed: C2.1, U2.21 (BTST)
unnamed: R7.2, U2.4 (STAT)
unnamed: R4.1, U3.8 (PG)
unnamed: L2.1, U3.7 (SW)
PMID: C10.2, U2.23 (PMID)
REGN: C1.2, R8.1, R9.1, U2.22 (REGN)
SYS: C3.1, C4.1, C9.2, C14.2, C15.2, C30.2, C31.1, D2.2 (A), D3.2 (A), L1.2, U2.15 (SYS), U2.16 (SYS), U3.2 (VIN), U3.3 (EN)
TS: R9.2, R10.1, TH1.1, U2.11 (TS)
VUSB: C5.1, C7.1, C8.1, D1.1, J2.A4_B9 (VBUS), J2.B4_A9 (VBUS__1), U2.1 (VBUS)

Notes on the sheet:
Charging USB
ESD protection
Charging circuit
3.3V buck

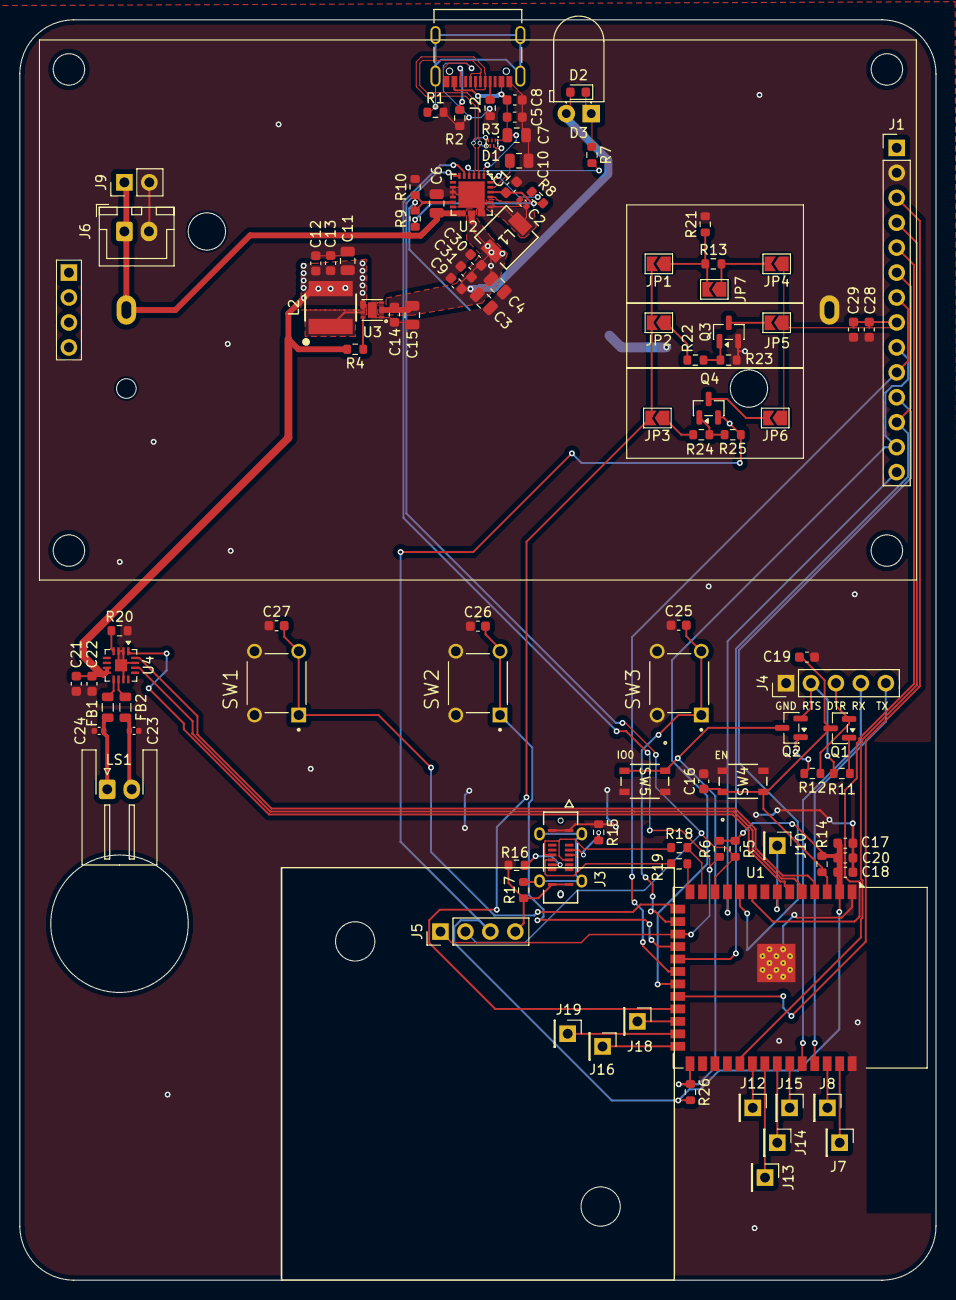
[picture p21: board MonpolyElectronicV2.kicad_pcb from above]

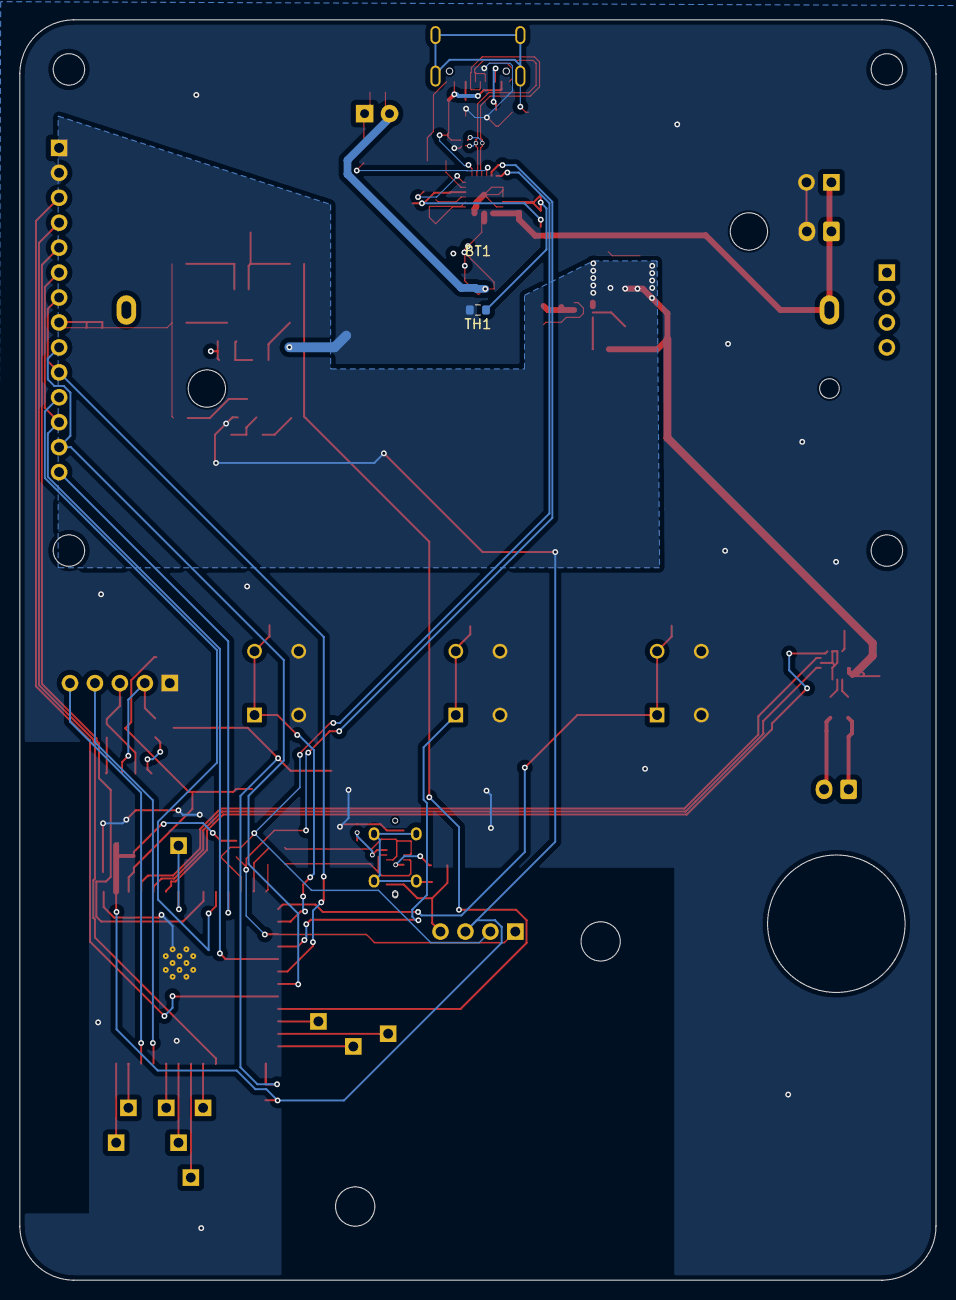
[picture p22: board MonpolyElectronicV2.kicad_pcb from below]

Board: 2 copper layers, 93.3 x 128.3 mm, 104 parts (2 on the bottom side), 76 nets.

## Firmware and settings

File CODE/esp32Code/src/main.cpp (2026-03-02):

#include <Arduino.h>

#include <stdarg.h>
#include <stdio.h>
#include <string.h>

#include "battery_manager.h"
#include "card_manager.h"
#include "config.h"
#include "display_ui.h"
#include "game_logic.h"
#include "nfc_manager.h"
#include "sound_manager.h"

namespace {
NfcManager nfc;
CardManager *cards = nullptr;
GameLogic game;
DisplayUi ui;
BatteryManager battery;
SoundManager sound;

uint32_t lastRenderMs = 0;
UiState lastState = UiState::HOME;

struct ButtonInput {
  int pin = -1;
  bool stablePressed = false;
  bool rawPressed = false;
  uint32_t lastDebounceMs = 0;
  uint32_t pressStartMs = 0;
};

ButtonInput btn1;
ButtonInput btn2;
ButtonInput btn3;

enum class ButtonPress : uint8_t { None, Short, Long };
enum class ProgramCategory : uint8_t { Player, Property, Event };
enum class AppMode : uint8_t { LobbyRegister, Running };

constexpr uint32_t LONG_PRESS_MS = 700;
constexpr uint32_t PROGRAM_MODE_HOLD_MS = 5000;

bool programmingMode = false;
bool programArmed = false;
ProgramCategory programCategory = ProgramCategory::Player;
uint8_t programIndex = 0;
char programDetail[40] = {0};
char programMessage[40] = {0};
uint32_t programMessageUntilMs = 0;
uint32_t comboHoldStartMs = 0;
bool comboLatch = false;
bool uiDirty = true;
int8_t lastWaitAnimPhase = -1;

AppMode appMode = AppMode::LobbyRegister;
bool activeLobbyPlayers[GAME_MAX_PLAYERS] = {false};
bool fundedLobbyPlayers[GAME_MAX_PLAYERS] = {false};
uint8_t registeredCount = 0;
uint8_t requiredPlayerCount = 0;
char lobbyMessage[40] = {0};

bool actionMenuOpen = false;
uint8_t actionMenuIndex = 0;

void logLine(const char *text) {
  Serial.println(text);
  Serial0.println(text);
}

void logf(const char *fmt, ...) {
  char buf[160];
  va_list args;
  va_start(args, fmt);
  vsnprintf(buf, sizeof(buf), fmt, args);
  va_end(args);
  Serial.println(buf);
  Serial0.println(buf);
}

void setLobbyMessage(const char *msg) {
  strncpy(lobbyMessage, msg, sizeof(lobbyMessage) - 1);
  lobbyMessage[sizeof(lobbyMessage) - 1] = '\0';
  uiDirty = true;
}

void clearLobbyData() {
  for (uint8_t i = 0; i < GAME_MAX_PLAYERS; i++) {
    activeLobbyPlayers[i] = false;
    fundedLobbyPlayers[i] = false;
  }
  registeredCount = 0;
  requiredPlayerCount = 0;
  setLobbyMessage(TXT("tap player cards", "toca cartas de jugador"));
}

const char *stateName(UiState state) {
  switch (state) {
    case UiState::HOME:
      return "HOME";
    case UiState::WAIT_CARD:
      return "WAIT_CARD";
    case UiState::PROPERTY_UNOWNED:
      return "PROPERTY_UNOWNED";
    case UiState::PROPERTY_OWNED:
      return "PROPERTY_OWNED";
    case UiState::EVENT:
      return "EVENT";
    case UiState::AUCTION:
      return "AUCTION";
    case UiState::DEBT:
      return "DEBT";
    case UiState::GO:
      return "GO";
    case UiState::TRAIN:
      return "TRAIN";
    case UiState::JAIL:
      return "JAIL";
    case UiState::WINNER:
      return "WINNER";
  }
  return "UNKNOWN";
}

void logStateTransition(const char *reason) {
  const UiState now = game.state();
  if (now == lastState) return;
  logf("[STATE] %s -> %s (%s)", stateName(lastState), stateName(now), reason);
  lastState = now;
}

void printUid(const CardTap &tap) {
  Serial.print("UID=");
  Serial0.print("UID=");
  for (uint8_t i = 0; i < tap.uidLen; i++) {
    if (tap.uid[i] < 0x10) {
      Serial.print('0');
      Serial0.print('0');
    }
    Serial.print(tap.uid[i], HEX);
    Serial0.print(tap.uid[i], HEX);
  }
}

ButtonPress pollButton(ButtonInput &btn) {
  const bool raw = digitalRead(btn.pin) == LOW;
  const uint32_t now = millis();

  if (raw != btn.rawPressed) {
    btn.rawPressed = raw;
    btn.lastDebounceMs = now;
  }

  if ((now - btn.lastDebounceMs) < BTN_DEBOUNCE_MS) {
    return ButtonPress::None;
  }

  if (btn.stablePressed != btn.rawPressed) {
    btn.stablePressed = btn.rawPressed;
    if (btn.stablePressed) {
      btn.pressStartMs = now;
      return ButtonPress::None;
    }
    const uint32_t heldMs = now - btn.pressStartMs;
    return heldMs >= LONG_PRESS_MS ? ButtonPress::Long : ButtonPress::Short;
  }

  return ButtonPress::None;
}

const char *programCategoryName(ProgramCategory cat) {
  switch (cat) {
    case ProgramCategory::Player:
      return TXT("PLAYER", "JUGADOR");
    case ProgramCategory::Property:
      return TXT("PROPERTY", "PROPIEDAD");
    case ProgramCategory::Event:
      return TXT("CHANCE", "SUERTE");
  }
  return "?";
}

void logProgramSelection() {
  logf("[PROG] category=%s number=%u", programCategoryName(programCategory), programIndex + 1);
}

uint8_t maxIndexForCategory(ProgramCategory cat) {
  if (cat == ProgramCategory::Player) return GAME_MAX_PLAYERS - 1;
  if (cat == ProgramCategory::Property) return 27;
  return 5;
}

void setProgramMessage(const char *msg, uint32_t holdMs = 1000) {
  strncpy(programMessage, msg, sizeof(programMessage) - 1);
  programMessage[sizeof(programMessage) - 1] = '\0';
  programMessageUntilMs = millis() + holdMs;
  uiDirty = true;
}

void updateProgramDetail() {
  if (programCategory == ProgramCategory::Player) {
    snprintf(programDetail, sizeof(programDetail), "ID %u BAL %u", programIndex + 1, STARTING_MONEY);
    logProgramSelection();
    uiDirty = true;
    return;
  }
  if (programCategory == ProgramCategory::Property) {
    const uint8_t id = programIndex + 1;
    const uint16_t price = game.propertyPrice(id);
    snprintf(programDetail, sizeof(programDetail), "#%u COST %u", id, price);
    logProgramSelection();
    uiDirty = true;
    return;
  }

  static const int16_t values[] = {200, -150, 0, 1, 100, -200};
  static const char *types[] = {"MONEY+", "MONEY-", "JAIL", "RENT+", "MONEY+", "MONEY-"};
  snprintf(programDetail, sizeof(programDetail), "#%u %s %d", programIndex + 1, types[programIndex], values[programIndex]);
  logProgramSelection();
  uiDirty = true;
}

void switchCategory(int dir) {
  int next = static_cast<int>(programCategory) + dir;
  if (next < 0) next = 2;
  if (next > 2) next = 0;
  programCategory = static_cast<ProgramCategory>(next);
  const uint8_t max = maxIndexForCategory(programCategory);
  if (programIndex > max) programIndex = max;
  updateProgramDetail();
}

void moveItem(int dir) {
  const int max = maxIndexForCategory(programCategory);
  int next = static_cast<int>(programIndex) + dir;
  if (next < 0) next = max;
  if (next > max) next = 0;
  programIndex = static_cast<uint8_t>(next);
  updateProgramDetail();
}

void handleButtons() {
  const ButtonPress b1 = pollButton(btn1);
  const ButtonPress b2 = pollButton(btn2);
  const ButtonPress b3 = pollButton(btn3);

  if (programmingMode) {
    if (b1 == ButtonPress::Short) {
      moveItem(-1);
      logLine("[PROG] item back");
      sound.beepTick();
    } else if (b1 == ButtonPress::Long) {
      switchCategory(-1);
      logLine("[PROG] prev category");
      sound.beepTick();
    }

    if (b3 == ButtonPress::Short) {
      moveItem(1);
      logLine("[PROG] item next");
      sound.beepTick();
    } else if (b3 == ButtonPress::Long) {
      switchCategory(1);
      logLine("[PROG] next category");
      sound.beepTick();
    }

    if (b2 == ButtonPress::Short) {
      programArmed = true;
      setProgramMessage(TXT("TAP CARD", "TOCA CARTA"), 2000);
      logLine("[PROG] arm write, waiting for card");
      sound.beepTick();
      uiDirty = true;
    }
    return;
  }

  if (appMode == AppMode::LobbyRegister) {
    if (b1 == ButtonPress::Short) {
      clearLobbyData();
      logLine("[LOBBY] cleared");
      sound.beepTick();
    }
    if (b3 == ButtonPress::Short) {
      if (registeredCount >= 2) {
        requiredPlayerCount = registeredCount;
        for (uint8_t i = 0; i < GAME_MAX_PLAYERS; i++) {
          if (!activeLobbyPlayers[i]) continue;
          fundedLobbyPlayers[i] = true;
          game.primePlayer(i + 1, STARTING_MONEY);
        }
        appMode = AppMode::Running;
        setLobbyMessage(TXT("players funded, game start", "jugadores con saldo, inicia juego"));
        logf("[LOBBY] game start with %u players", requiredPlayerCount);
        sound.beepOk();
      } else {
        setLobbyMessage(TXT("need at least 2 players", "se necesitan al menos 2 jugadores"));
        sound.beepError();
      }
    }
    return;
  }

  // Physical mapping:
  // BTN1 = X (cancel/back), BTN2 = M (mode/special), BTN3 = CHECK (confirm)
  if (actionMenuOpen) {
    if (b2 == ButtonPress::Short) {
      actionMenuIndex = (actionMenuIndex + 1) % 3;
      uiDirty = true;
      sound.beepTick();
      logf("[MENU] next option=%u", actionMenuIndex);
    }
    if (b1 == ButtonPress::Short) {
      actionMenuOpen = false;
      uiDirty = true;
      sound.beepTick();
      logLine("[MENU] close");
    }
    if (b3 == ButtonPress::Short) {
      actionMenuOpen = false;
      game.triggerMenuAction(actionMenuIndex);
      uiDirty = true;
      sound.beepOk();
      logf("[MENU] selected option=%u", actionMenuIndex);
      logStateTransition("MENU_SELECT");
    }
    return;
  }

  if (b1 == ButtonPress::Short) {
    logLine("[BTN] X pressed");
    game.onBtn2();
    sound.beepTick();
    logStateTransition("X");
  }
  if (b2 == ButtonPress::Short) {
    if (game.state() == UiState::HOME) {
      actionMenuOpen = true;
      actionMenuIndex = 0;
      uiDirty = true;
      sound.beepTick();
      logLine("[MENU] open");
    } else {
      logLine("[BTN] M pressed");
      game.onBtn3();
      sound.beepTick();
      logStateTransition("M");
    }
  }
  if (b3 == ButtonPress::Short) {
    logLine("[BTN] CHECK pressed");
    game.onBtn1();
    sound.beepTick();
    logStateTransition("CHECK");
  }
}

void handleProgramCombo() {
  const bool hold = (digitalRead(PIN_BTN1) == LOW) && (digitalRead(PIN_BTN3) == LOW);
  const uint32_t now = millis();

  if (!hold) {
    comboHoldStartMs = 0;
    comboLatch = false;
    return;
  }

  if (comboLatch) {
    return;
  }
  if (comboHoldStartMs == 0) {
    comboHoldStartMs = now;
    return;
  }
  if (now - comboHoldStartMs < PROGRAM_MODE_HOLD_MS) {
    return;
  }

  comboLatch = true;
  programmingMode = !programmingMode;
  programArmed = false;
  if (programmingMode) {
    programCategory = ProgramCategory::Player;
    programIndex = 0;
    updateProgramDetail();
    setProgramMessage(TXT("PROGRAM MODE", "MODO PROGRAMA"), 1200);
    logLine("[PROG] enabled");
  } else {
    setProgramMessage(TXT("PROGRAM OFF", "PROGRAMA OFF"), 1200);
    logLine("[PROG] disabled");
  }
  sound.beepOk();
  uiDirty = true;
}

void handleCardTap() {
  CardTap tap{};
  if (!nfc.poll(tap)) return;

  if (programmingMode) {
    if (!programArmed) {
      logLine("[PROG] card ignored (press BTN2 to arm write)");
      sound.beepError();
      return;
    }

    bool ok = false;
    if (programCategory == ProgramCategory::Player) {
      PlayerCardData player{};
      player.playerId = programIndex + 1;
      player.balance = STARTING_MONEY;
      player.jailed = 0;
      player.bankrupt = 0;
      ok = cards->writePlayer(tap, player);
      logf("[PROG] write player id=%u result=%s", player.playerId, ok ? "ok" : "fail");
    } else if (programCategory == ProgramCategory::Property) {
      const uint8_t id = programIndex + 1;
      PropertyCardData property{};
      property.propertyId = id;
      property.ownerId = 0;
      property.level = 1;
      property.basePrice = game.propertyPrice(id);
      ok = cards->writeProperty(tap, property);
      logf("[PROG] write place id=%u price=%u result=%s", id, property.basePrice, ok ? "ok" : "fail");
    } else {
      EventCardData event{};
      event.eventId = programIndex + 1;
      if (programIndex == 0) {
        event.type = EventType::MONEY;
        event.value = 200;
      } else if (programIndex == 1) {
        event.type = EventType::MONEY;
        event.value = -150;
      } else if (programIndex == 2) {
        event.type = EventType::JAIL;
        event.value = 0;
      } else if (programIndex == 3) {
        event.type = EventType::RENT_BOOST;
        event.value = 1;
      } else if (programIndex == 4) {
        event.type = EventType::MONEY;
        event.value = 100;
      } else {
        event.type = EventType::MONEY;
        event.value = -200;
      }
      ok = cards->writeEvent(tap, event);
      logf("[PROG] write special id=%u result=%s", event.eventId, ok ? "ok" : "fail");
    }

    printUid(tap);
    Serial.println();
    Serial0.println();
    if (ok) {
      setProgramMessage(TXT("WRITE OK", "GRABADO OK"), 1200);
      sound.beepOk();
    } else {
      setProgramMessage(TXT("WRITE FAIL", "GRABADO FAIL"), 1200);
      sound.beepError();
    }
    programArmed = false;
    return;
  }

  if (appMode == AppMode::LobbyRegister) {
    PlayerCardData player{};
    if (!cards->readPlayer(tap, player)) {
      setLobbyMessage(TXT("tap a PLAYER card", "toca una carta de JUGADOR"));
      sound.beepError();
      return;
    }
    if (player.playerId < 1 || player.playerId > GAME_MAX_PLAYERS) {
      setLobbyMessage(TXT("player id out of range", "id de jugador fuera de rango"));
      sound.beepError();
      return;
    }
    const uint8_t idx = player.playerId - 1;
    if (!activeLobbyPlayers[idx]) {
      activeLobbyPlayers[idx] = true;
      registeredCount++;
      logf("[LOBBY] registered player=%u total=%u", player.playerId, registeredCount);
    }
    setLobbyMessage(TXT("player registered", "jugador registrado"));
    uiDirty = true;
    sound.beepOk();
    return;
  }

  NfcCardType type = cards->detectType(tap);
  if (type == NfcCardType::PLAYER) {
    PlayerCardData player{};
    if (cards->readPlayer(tap, player)) {
      if (appMode == AppMode::Running) {
        if (player.playerId < 1 || player.playerId > GAME_MAX_PLAYERS || !activeLobbyPlayers[player.playerId - 1]) {
          setLobbyMessage(TXT("player not in this game", "jugador fuera de esta partida"));
          uiDirty = true;
          sound.beepError();
          return;
        }
      }
      logf("[NFC] player card scanned id=%u balance=%ld jailed=%u bankrupt=%u", player.playerId, (long)player.balance, player.jailed, player.bankrupt);
      printUid(tap);
      Serial.println();
      Serial0.println();
    } else {
      Serial.print("[NFC] player card scanned (read failed) ");
      Serial0.print("[NFC] player card scanned (read failed) ");
      printUid(tap);
      Serial.println();
      Serial0.println();
    }
    game.onPlayerCard(tap, *cards);
    sound.beepOk();
    logStateTransition("PLAYER_CARD");
    return;
  }
  if (type == NfcCardType::PROPERTY) {
    PropertyCardData property{};
    if (cards->readProperty(tap, property)) {
      logf("[NFC] property card scanned id=%u owner=%u level=%u price=%u", property.propertyId, property.ownerId, property.level, property.basePrice);
      printUid(tap);
      Serial.println();
      Serial0.println();
    } else {
      Serial.print("[NFC] property card scanned (read failed) ");
      Serial0.print("[NFC] property card scanned (read failed) ");
      printUid(tap);
      Serial.println();
      Serial0.println();
    }
    game.onPropertyCard(tap, *cards);
    sound.beepOk();
    logStateTransition("PROPERTY_CARD");
    return;
  }
  if (type == NfcCardType::EVENT) {
    EventCardData event{};
    if (cards->readEvent(tap, event)) {
      logf("[NFC] event card scanned id=%u type=%u value=%d", event.eventId, static_cast<uint8_t>(event.type), event.value);
      printUid(tap);
      Serial.println();
      Serial0.println();
    } else {
      Serial.print("[NFC] event card scanned (read failed) ");
      Serial0.print("[NFC] event card scanned (read failed) ");
      printUid(tap);
      Serial.println();
      Serial0.println();
    }
    game.onEventCard(tap, *cards);
    sound.beepOk();
    logStateTransition("EVENT_CARD");
    return;
  }

  Serial.print("[NFC] unknown card scanned ");
  Serial0.print("[NFC] unknown card scanned ");
  printUid(tap);
  Serial.println();
  Serial0.println();
  sound.beepError();
}

void refreshUi(bool force = false) {
  const uint32_t now = millis();
  if (programMessageUntilMs > 0 && now >= programMessageUntilMs) {
    programMessage[0] = '\0';
    programMessageUntilMs = 0;
    uiDirty = true;
  }

  bool animDirty = false;
  const bool waitAnim = (!programmingMode && appMode == AppMode::Running && !actionMenuOpen && game.state() == UiState::WAIT_CARD);
  if (waitAnim) {
    const int8_t phase = static_cast<int8_t>((now / 120) % 2);
    if (phase != lastWaitAnimPhase) {
      lastWaitAnimPhase = phase;
      animDirty = true;
    }
  } else {
    lastWaitAnimPhase = -1;
  }

  const bool gameDirty = (!programmingMode && appMode == AppMode::Running && !actionMenuOpen && game.isDirty());
  const bool needsRender = force || uiDirty || gameDirty || animDirty;

  if (!needsRender) {
    return;
  }

  if (programmingMode) {
    ui.renderProgramming(programCategoryName(programCategory), programIndex + 1, programDetail, programArmed, programMessage);
  } else if (appMode != AppMode::Running) {
    ui.renderLobby(registeredCount, registeredCount, activeLobbyPlayers, false, lobbyMessage);
  } else if (actionMenuOpen) {
    ui.renderActionMenu(actionMenuIndex);
  } else {
    ui.render(game, battery.readPercent());
    game.clearDirty();
  }

  uiDirty = false;
  lastRenderMs = now;
}
}  // namespace

void setup() {
  Serial.begin(115200);
  Serial0.begin(115200);
  delay(100);
  logLine("[BOOT] booting...");
  logLine("[BOOT] RAM_MODE: gameplay money/property kept in memory (no gameplay card writes)");

  pinMode(PIN_BTN1, INPUT_PULLUP);
  pinMode(PIN_BTN2, INPUT_PULLUP);
  pinMode(PIN_BTN3, INPUT_PULLUP);

  btn1.pin = PIN_BTN1;
  btn2.pin = PIN_BTN2;
  btn3.pin = PIN_BTN3;

  battery.begin();
  logLine("[BOOT] battery manager ready");
  sound.begin();
  logLine("[BOOT] sound manager ready");
  ui.begin();
  logLine("[BOOT] display ready");

  const bool nfcOk = nfc.begin();
  logf("[BOOT] nfc init: %s", nfcOk ? "ok" : "failed");
  cards = new CardManager(nfc.driver());

  game.begin();
  clearLobbyData();
  appMode = AppMode::LobbyRegister;
  updateProgramDetail();
  lastState = game.state();
  logf("[BOOT] game state: %s", stateName(lastState));
  if (!nfcOk) {
    game.onBtn2();
    logStateTransition("NFC_FAIL_FALLBACK");
  }

  refreshUi(true);
  logLine("[BOOT] running");
}

void loop() {
  handleProgramCombo();
  handleButtons();
  handleCardTap();
  if (!programmingMode && appMode == AppMode::Running && !actionMenuOpen) {
    game.onTick();
    logStateTransition("TICK");
  }
  refreshUi();
}

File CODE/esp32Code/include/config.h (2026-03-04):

#pragma once
#include <Arduino.h>

// =============================================================================
// LANGUAGE (compile-time)
// - Default build is English.
// - Build Spanish with: pio run -e esp32-s3-es
// =============================================================================
#if defined(UI_LANG_ES)
  #define TXT(en, es) es
#else
  #define TXT(en, es) en
#endif

// =============================================================================
// DEBUG
// =============================================================================
#ifndef DEBUG
  #define DEBUG 0
#endif

#if DEBUG
  #define DBG(fmt, ...)   Serial.printf("[DBG] " fmt "\n", ##__VA_ARGS__)
  #define DBG_PRINT(msg)  Serial.println(F("[DBG] " msg))
#else
  #define DBG(fmt, ...)   ((void)0)
  #define DBG_PRINT(msg)  ((void)0)
#endif

// =============================================================================
// PIN DEFINITIONS
// =============================================================================

// Display pins (ST7789 SPI)
#define PIN_TFT_CS      14
#define PIN_TFT_DC      16
#define PIN_TFT_RST     38
#define PIN_TFT_SCLK    12
#define PIN_TFT_MOSI    11
#define PIN_TFT_MISO    13
#define PIN_TFT_BL      21

// Touch
#define PIN_TOUCH_IRQ    18

// NFC PN532 (I2C)
#define PIN_NFC_SDA      8
#define PIN_NFC_SCL      9
#define PIN_NFC_IRQ      -1
#define PIN_NFC_RST      -1

// Physical buttons (active LOW, use INPUT_PULLUP)
#define PIN_BTN_LEFT     3
#define PIN_BTN_CENTER   10
#define PIN_BTN_RIGHT    46

// Speaker / buzzer
#define PIN_SPEAKER      4

// Battery ADC
#define PIN_BATTERY_ADC  1

// Button aliases used by current firmware modules
#define PIN_BTN1         PIN_BTN_LEFT
#define PIN_BTN2         PIN_BTN_CENTER
#define PIN_BTN3         PIN_BTN_RIGHT

// =============================================================================
// DISPLAY SPI SPEED (compile-time override)
// Example: -DTFT_SPI_HZ=4000000
// =============================================================================
#ifndef TFT_SPI_HZ
  #define TFT_SPI_HZ 8000000
#endif

// =============================================================================
// DISPLAY
// =============================================================================
#define SCREEN_W         320
#define SCREEN_H         240

// Rotate screen 180 degrees from the default orientation.
// Set to 0 to use the default orientation.
#ifndef TFT_ROTATE_180
  #define TFT_ROTATE_180 1
#endif

// =============================================================================
// GAME CONSTANTS
// =============================================================================
#define MAX_PLAYERS          8
#define MAX_NAME_LEN         12
#define STARTING_MONEY       1500
#define GO_SALARY            200
#define JAIL_POSITION        10
#define GO_TO_JAIL_POS       30
#define JAIL_FINE            50
#define INCOME_TAX_AMT       200
#define LUXURY_TAX_AMT       100
#define BOARD_SIZE           40
#define MAX_HOUSES           5      // 5 = hotel
#define TOTAL_HOUSES         32     // Bank's supply
#define TOTAL_HOTELS         12
#define NUM_CHANCE_CARDS     16
#define NUM_COMMUNITY_CARDS  16

// =============================================================================
// NFC CARD TYPES  (byte 0 of sector 1 block 4)
// =============================================================================
#define NFC_TYPE_PLAYER      0x01
#define NFC_TYPE_PROPERTY    0x02
#define NFC_TYPE_EVENT       0x03

// =============================================================================
// TIMING
// =============================================================================
#define BTN_DEBOUNCE_MS      50
#define TOUCH_DEBOUNCE_MS    100
#define SPLASH_DURATION_MS   2500
#define DICE_ANIM_MS         1200
#define NFC_POLL_INTERVAL_MS 300

// Timing aliases used by current firmware modules
#define NFC_POLL_MS       140
#define CARD_DEBOUNCE_MS  1200
#define WAIT_TIMEOUT_MS   20000
#define HOME_REFRESH_MS   500


// =============================================================================
// GAME SETTINGS (run-time adjustable)
// =============================================================================
struct GameSettings {
    uint32_t startingMoney   = STARTING_MONEY;
    bool     freeParkingPool = true;
    uint8_t  jailMaxTurns    = 3;
    bool     autoRent        = true;
    bool     nfcRequired     = false;
    uint8_t  diceSpeed       = 2;        // 1-3
    uint8_t  volume          = 3;        // 0-5
};

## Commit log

2025-10-04 Place most parts and start Power schematic
    [Logic.kicad_sch, MonpolyElectronicV2.kicad_pcb, MonpolyElectronicV2.kicad_sch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]
2025-10-06 continue battery circuit. Finished BQ25895RTWR and USB wiring
    [Power.kicad_sch]
2025-10-06 work on Logic part (MCU): audio done, programming done, ESP32 and inputs WIP, diplay not yet started
    [Logic.kicad_sch, Logic.sync-conflict-20251006-135926-LCY53NE.kicad_sch, MonpolyElectronicV2.kicad_sch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]
2025-10-07 find possible display
    [Logic.kicad_sch, Logic.sync-conflict-20251006-135926-LCY53NE.kicad_sch]
2025-10-08 Finish Schematic wiring
    [Logic.kicad_sch]
2025-10-08 Start adding footprints
    [Logic.kicad_sch, Power.kicad_sch]
2025-10-10 add symbols + multiple backlight options
    [MonpolyElectronicV2.kicad_sch, Power.kicad_sch]
2025-10-10 assign footprints + multiple backlight options
    [Logic.kicad_sch]
2025-10-10 add decoupling caps to TFT B_LED
    [Logic.kicad_sch]
2025-10-11 Add boxes to schematic
    [Logic.kicad_sch, Power.kicad_sch]
2025-10-11 fix DTR and RTS circuit
    [Logic.kicad_sch]
2025-10-11 Start component placing by groups: BQ25895RTWR, TPS62162DSG and 10155435-00011LF done
    [Logic.kicad_sch, MonpolyElectronicV2.kicad_pcb, MonpolyElectronicV2.kicad_sch]
2025-10-11 finish placement of all components
    [Logic.kicad_sch, MonpolyElectronicV2.kicad_pcb, Power.kicad_sch]
2025-10-11 finish placing components
    [Logic.kicad_sch, MonpolyElectronicV2.kicad_pcb]
2025-10-12 start routing top part of the pcb
    [MonpolyElectronicV2.kicad_pcb]
2025-10-13 Finish routing PCB
    [Logic.kicad_sch, MonpolyElectronicV2.kicad_pcb]
2025-10-13 start CAD
    [MAIN.FCStd, MonpolyElectronicV2.kicad_pcb]
2025-10-15 CAD base start
    [MAIN.FCStd, MonpolyElectronicV2.kicad_pcb]
2025-10-15 continue CAD
    [MAIN.FCStd]
2025-10-15 base done
    [MAIN.FCStd, MonpolyElectronicV2.kicad_pcb, Power.kicad_sch]
2025-10-15 continue on the cover, and design clipping mechanism
    [MAIN.FCStd]
2025-10-17 Finish CAD (hopefully)
    [MAIN.FCStd]
2025-10-17 battery tab
    [MAIN.FCStd]
2025-10-17 finish cad FR this time
2025-10-18 get repo ready
    [BOM.csv, CaseBase.step, CaseBatteryTab.step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]
2025-10-18 update BOM
    [BOM.csv]
2025-10-18 update BOM, again
    [BOM.csv]
2026-02-10 code uploads
    [BOM.csv, CaseBase.step, CaseBatteryTab.step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]
2026-02-10 fix text not displaying
    [config.h, hardware.cpp, nfc_handler.cpp]
2026-02-14 fix display not updating
    [main.cpp]
2026-02-15 use hardware SPI for faster redraw
2026-03-02 fix cards and some logic
    [config.h]
